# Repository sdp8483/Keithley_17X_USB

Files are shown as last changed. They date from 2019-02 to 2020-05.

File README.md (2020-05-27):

# Keithley 17x USB Adapter
The following device is used to connect the Keithley 177 and 179 digital multimeter to the PC. The USB Adapter is a serial COM port enabling the user to use simple serial terminal programs to read data from the Keithley multimeter. The device fully isolates the PC from the multimeter through optoisolators and has no impact on the meters performance. The Keithley 17x USB Adapter is a simple device for connecting two great multimeters to the PC to further increase their value to hobbyists by enabling data logging.

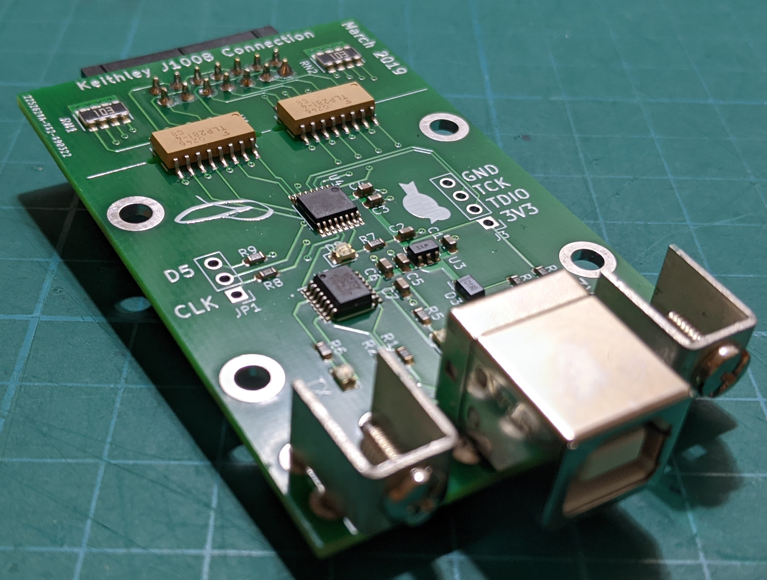
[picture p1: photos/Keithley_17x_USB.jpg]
Keithley 17x USB Adapter


 Top View | Bottom View   
----|-----    
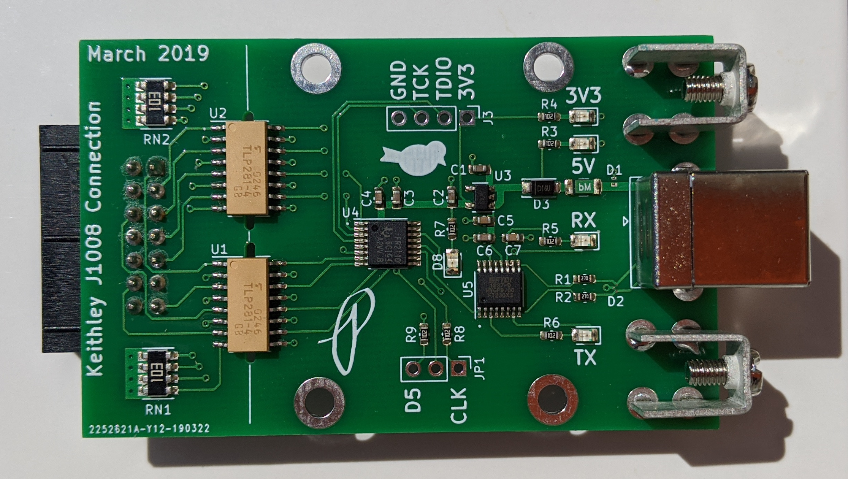
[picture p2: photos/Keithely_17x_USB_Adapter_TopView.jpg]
USB Adapter Top View
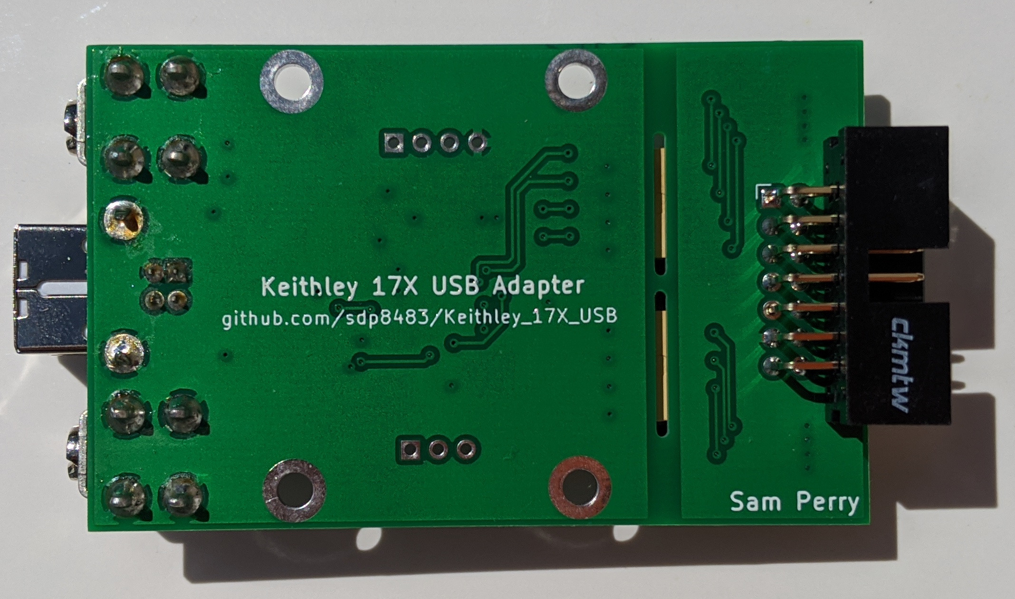
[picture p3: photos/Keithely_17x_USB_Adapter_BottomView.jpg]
USB Adapter Bottom View
 | 

The Keithley 177 and 179 Digital Multimeter have a GPIB option. If your meter has this option installed you may want to get a GPIB to USB adapter and use that. If your meter does not have this option installed then the Keithley 17x USB Adapter is for you. The original GPIB option was a daughter board that connected to the meter's main board using connector J1008. This connector is a 14 pin DIP socket located right behind the input terminals of the meter. Before continuing with the project I suggest you open up your meter and locate this connector. Below are pictures of the socket location on the three meters I have. If the socket is not soldered in but the footprint is on the PCB then don't worry. Get a suitable DIP socket and solder it in.

 Keithley 177 J1008 Location                                 | Keithley 179 J1008 Location
-------------------------------------------------------------|-------------------
177 J1008 Location| 179 J1008 Location

179 Birdseye View

# Building the PCB
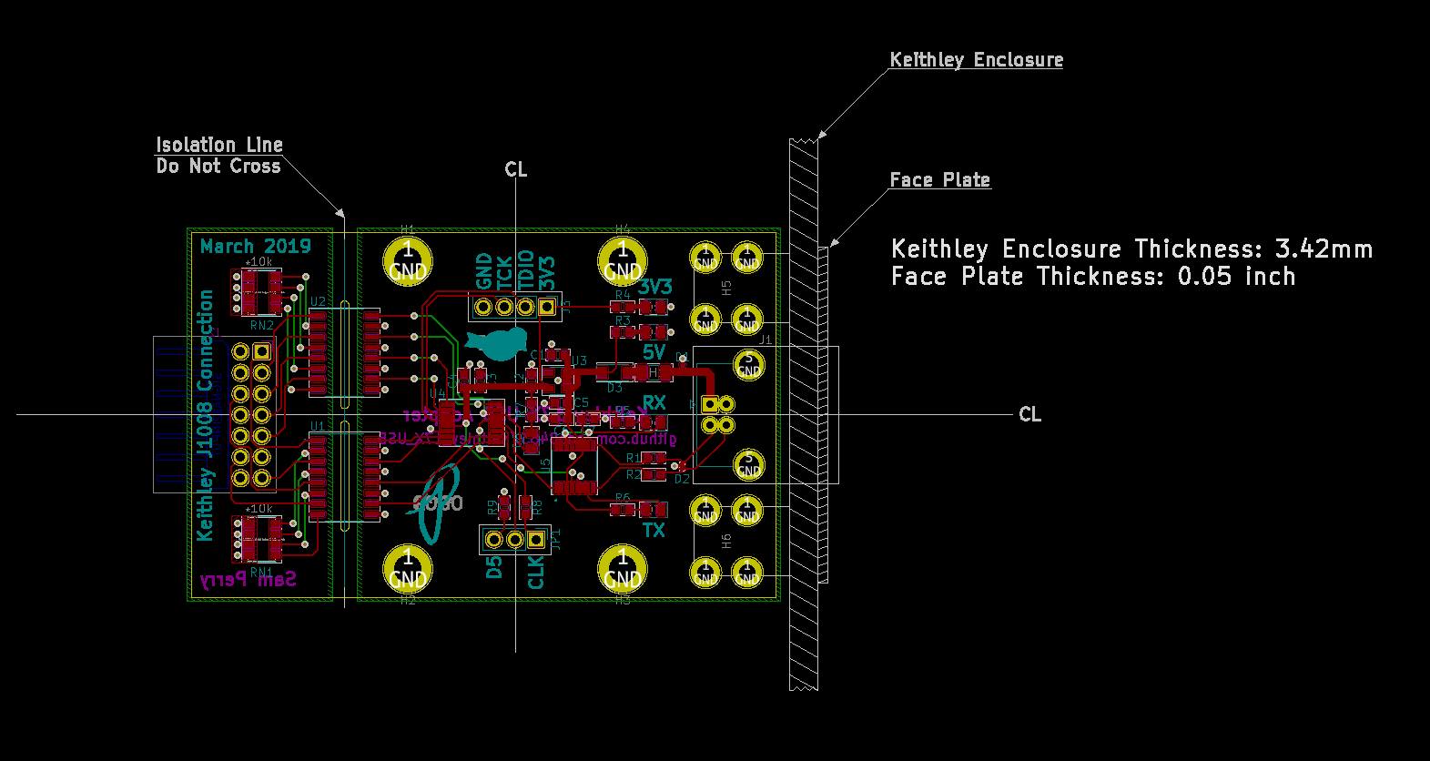
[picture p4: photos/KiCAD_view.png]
KiCAD View


1. Download the [GERBER](pcb/gerber) files and order from your favorite prototype PCB board house. The PCB is double sided and is 70.5mm x 40mm in size.

2. For reflow soldering I strongly suggest getting a solder paste stencil from your prototype PCB manufacture. If ordering thorough a board house that does not offer stencils then [OSH Stencils](https://www.oshstencils.com/#%20) is a low cost option. The polyimide film 3mil stencil is more then durable enough for a few boards and the cost is just about right. For hand soldering the solder paste stencil can be omitted.

3. Order the components listed in the [BOM](pcb/bom/Keithley_17x_USB_BOM.csv). All items were ordered from [DigiKey](https://www.digikey.com/) or [LCSC](https://lcsc.com/) but it is possible to source from other suppliers.

4. Use the [Interactive BOM](pcb/bom/ibom.html) for part placement during PCB assembly.

# Programing the MSP430FR2110
1. The lowest cost solution to obtain a programmer for the MSP430 is to buy a TI Launchpad. The [MSP-EXP430FR2433](http://www.ti.com/tool/MSP-EXP430FR2433) Launchpad is a good option but any TI Lauchpad that has an onboard eZ-FET debug probe will work.

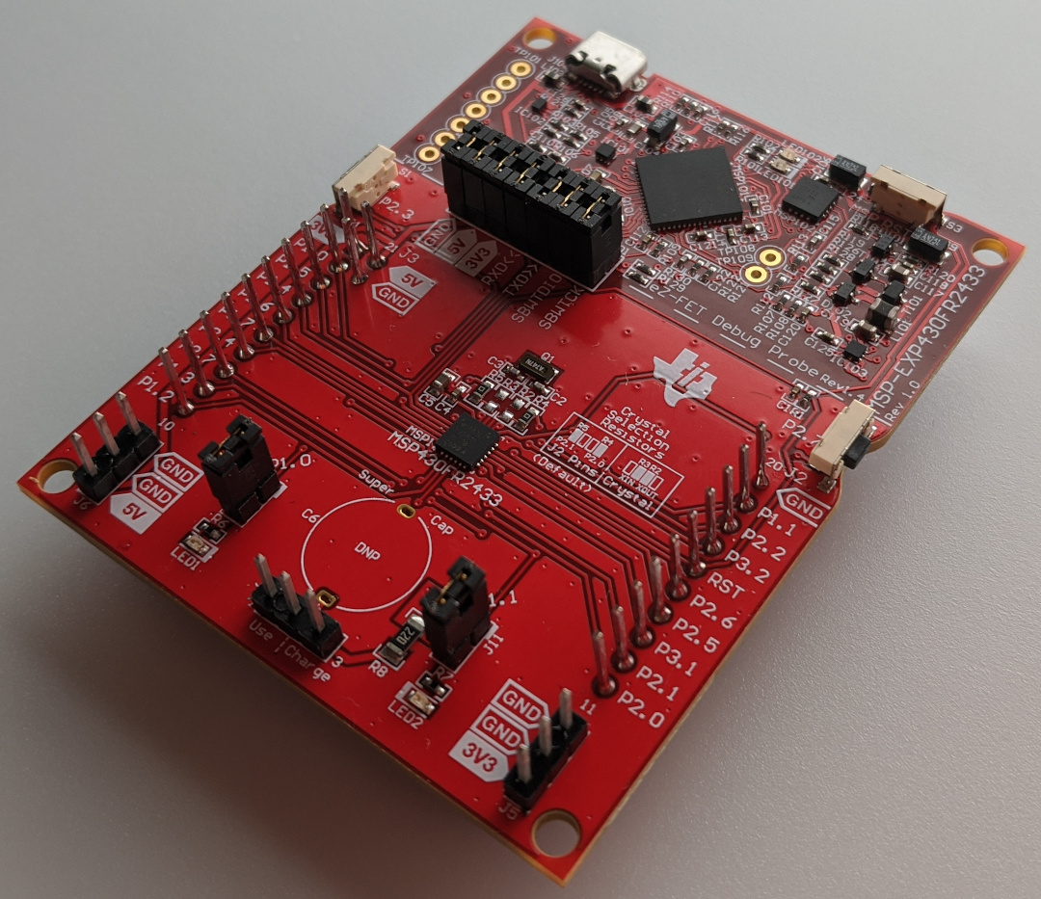
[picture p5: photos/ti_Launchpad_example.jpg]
MSP-EXP430FR2433


2. There are at least two software paths for uploading the firmware
    1. **TI UniFlash:** You can either install [UniFlash](http://www.ti.com/tool/UNIFLASH) or use the [UniFlash cloud tool](https://dev.ti.com/). The compiled code is in [firmware/releases](firmware/releases).

    2. **TI Code Composer Studio:** Install the latest version of [Code Composer Studio](http://www.ti.com/tool/CCSTUDIO), import the CCS project found in [firmware/keithley_17X_USB](firmware/keithley_17X_USB), and build the firmware yourself. There is also a [cloud version of CCS](https://dev.ti.com/) that you can use if you do not want to install software on your PC.

3. Remove all the jumpers from the TI Launchpad used to connect the eZ-FET to the onboard target microcontroller. Connect the eZ-FET to connector J3 on the Keithley 17x USB adapter. The pinout is labeled on the silkscreen. It is not necessary to solder a header onto the PCB, I programmed all my boards using female to male Dupont wires and held them in place while uploading the code.

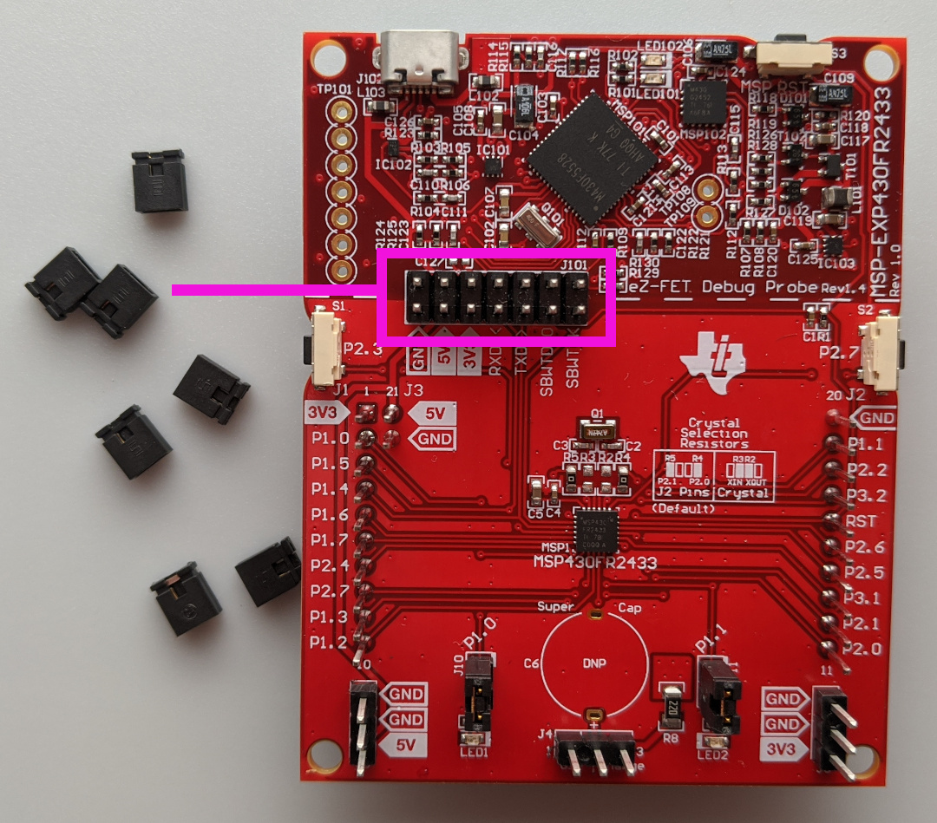
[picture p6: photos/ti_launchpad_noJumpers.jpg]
Remove Jumpers from Lauchpad


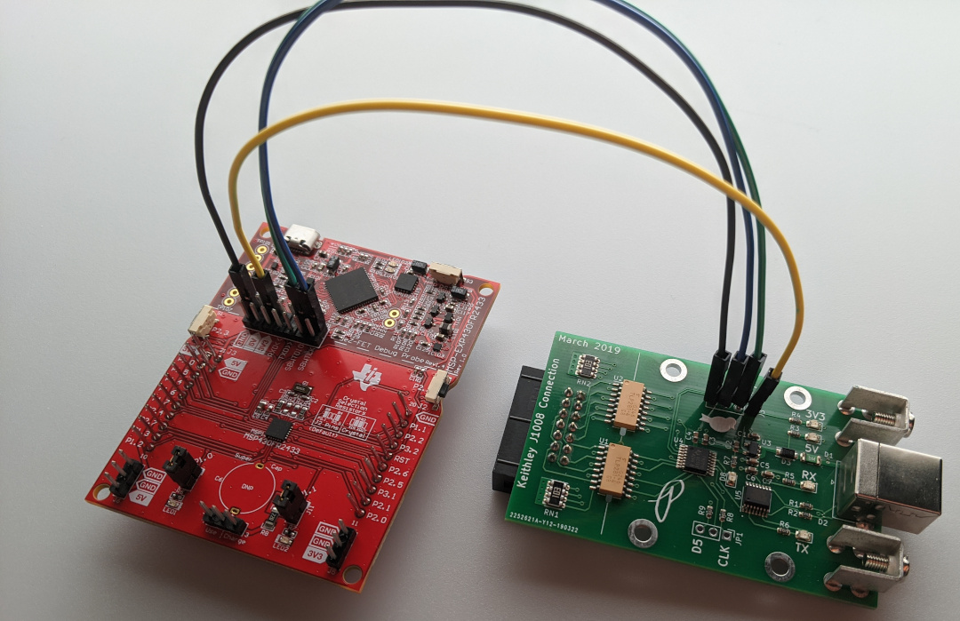
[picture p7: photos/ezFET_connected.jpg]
ezFET Connected


# Installing the USB Adapter into the Keithley Digital Multimeter
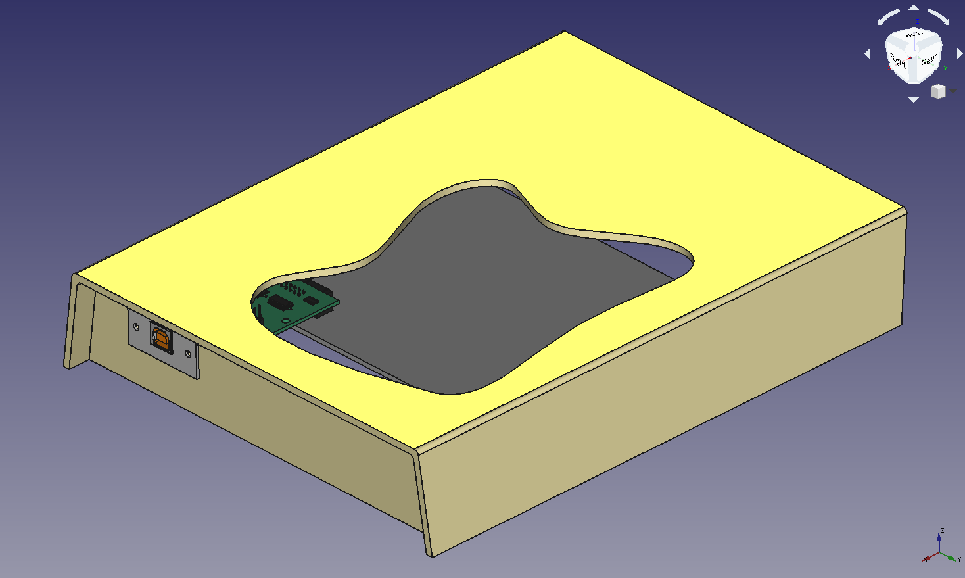
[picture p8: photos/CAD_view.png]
CAD View


1. Print and cutout the mounting hole locating [template](enclosure/Drawings/mounting_template.pdf).

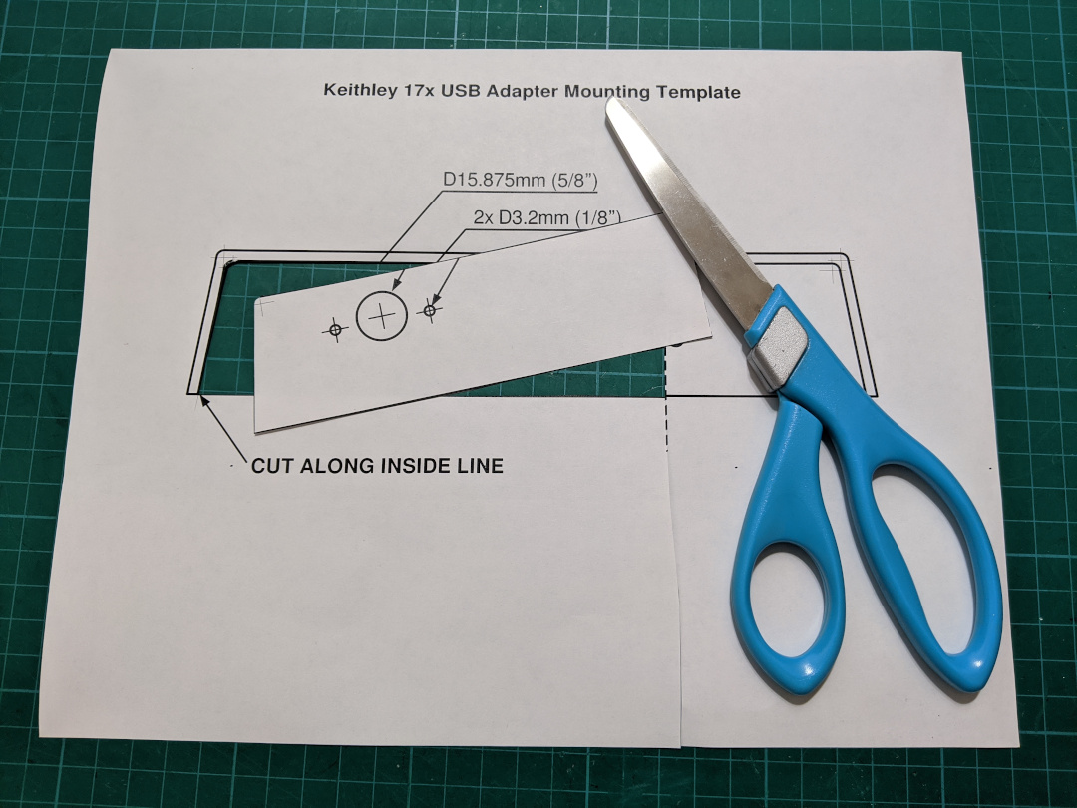
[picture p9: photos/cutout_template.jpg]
cutout template


2. Open up your digital multimeter. We need to add a few holes to the rear of the top case.

3. Using a punch and the hole locating template, mark the center of the mounting hole locations and the USB cutout.

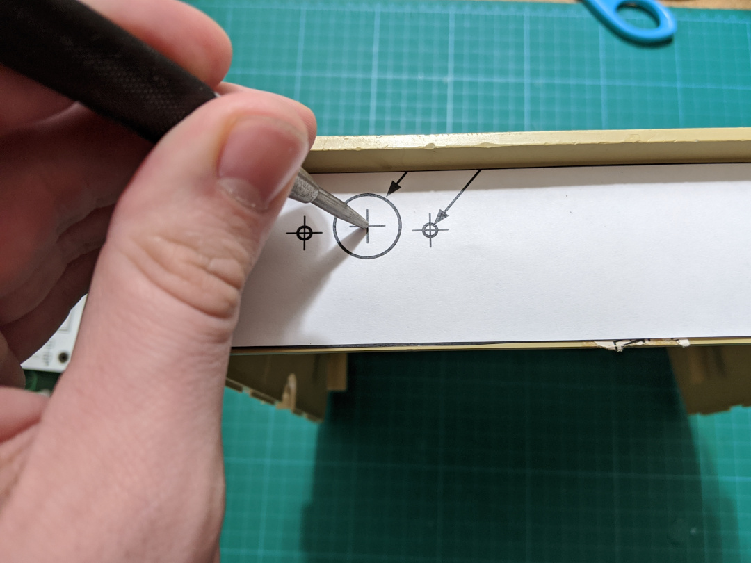
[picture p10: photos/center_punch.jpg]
center punch

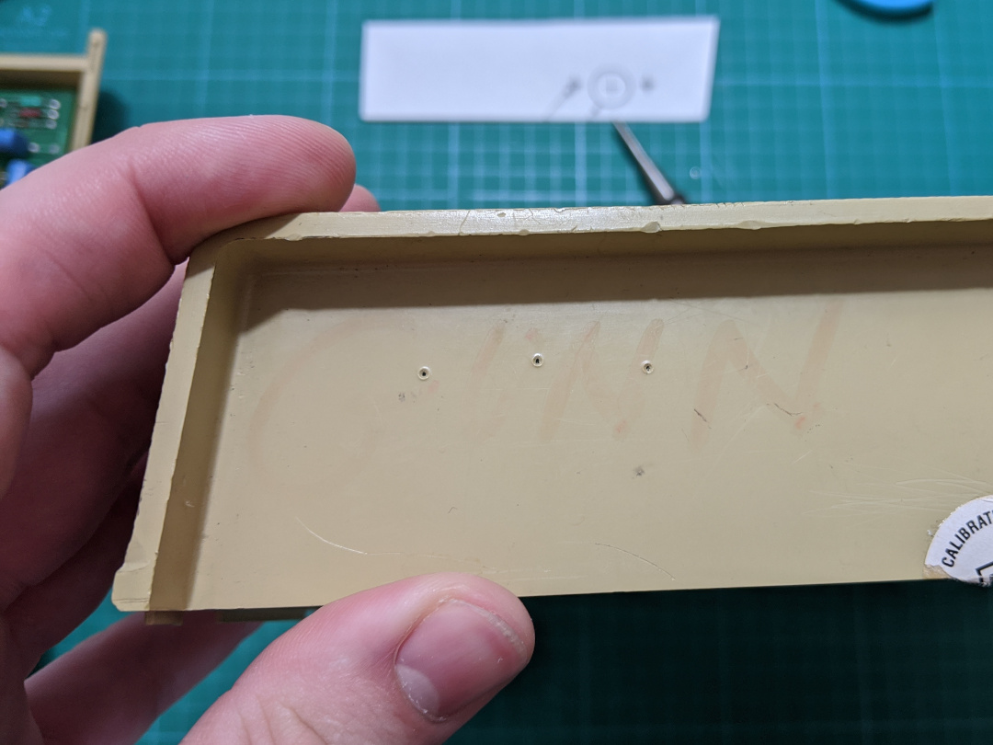
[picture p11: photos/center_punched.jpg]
center punched


4. Drill the mounting holes using a #29 [3.45mm] drill or closest metric size. Enjoy that old plastic smell coming from the fresh drilled hole.

5. I recommend pilot drilling the USB hole first, you can use the same size drill bit from the previous step. Then drill the USB cutout to 5/8" [15.875mm] or the closest metric size. I used a set of step drills so that the hole was gradually increased.
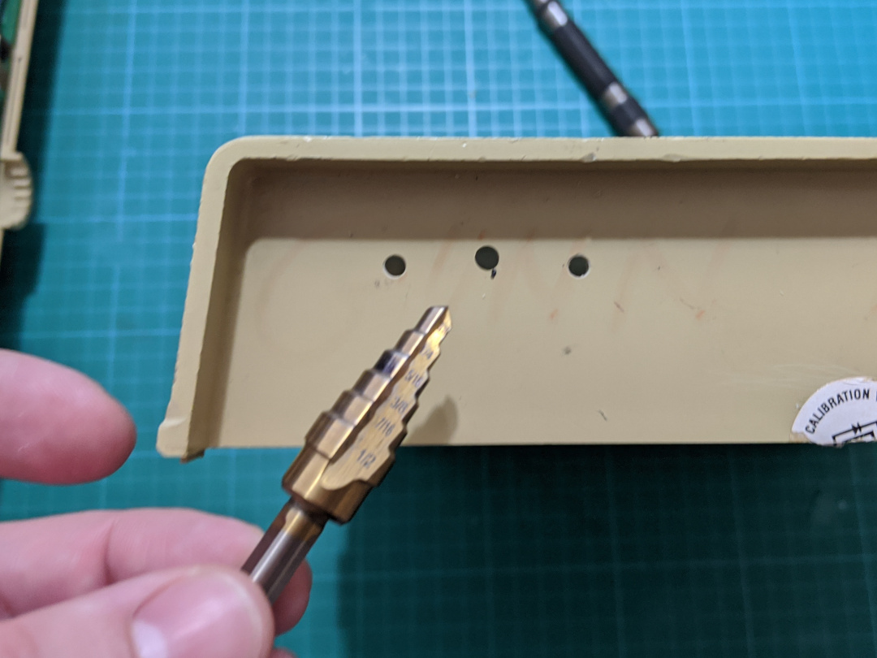
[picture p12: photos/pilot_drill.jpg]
pilot drill

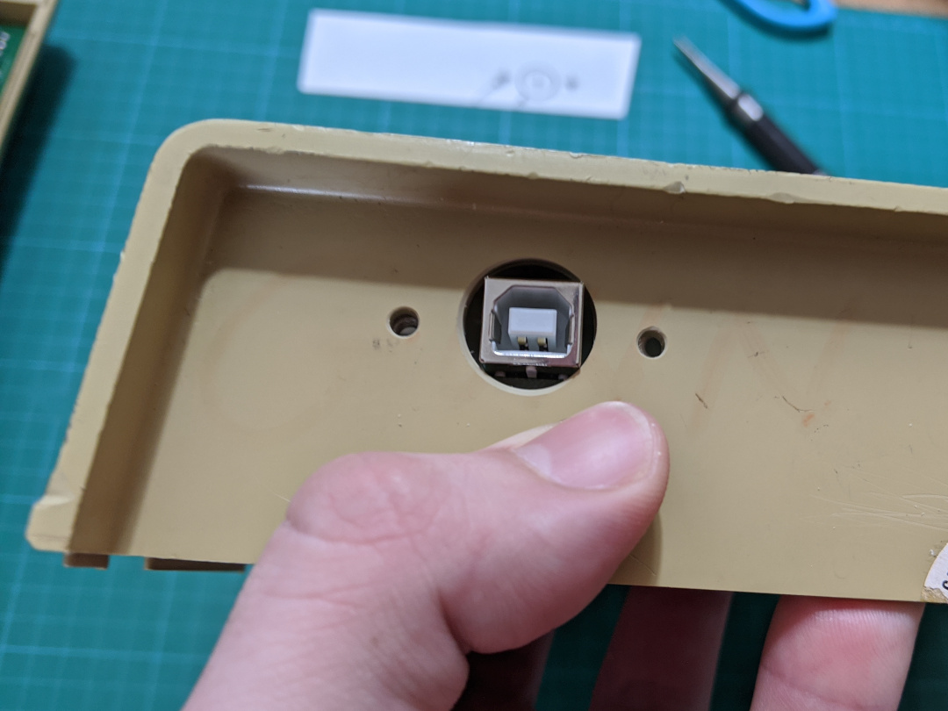
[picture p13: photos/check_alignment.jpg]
check holes


6. Don't forget to deburr the drilled holes.

7. Print off a [face plate](encloser/USB_face_plate.stl) so we can hide the gap around the circular cutout for the USB connector. Print at 0.2mm layer height. It's very thin so it should print fast, about 5 minutes on my Prusa clone. If you don't mind the gap you can skip this.

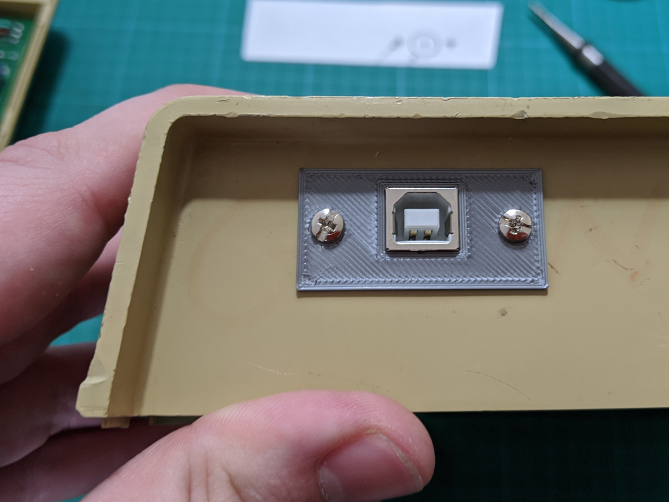
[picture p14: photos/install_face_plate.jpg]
install with faceplate


8. Place the top of the case to the right of the bottom of the multimeter.
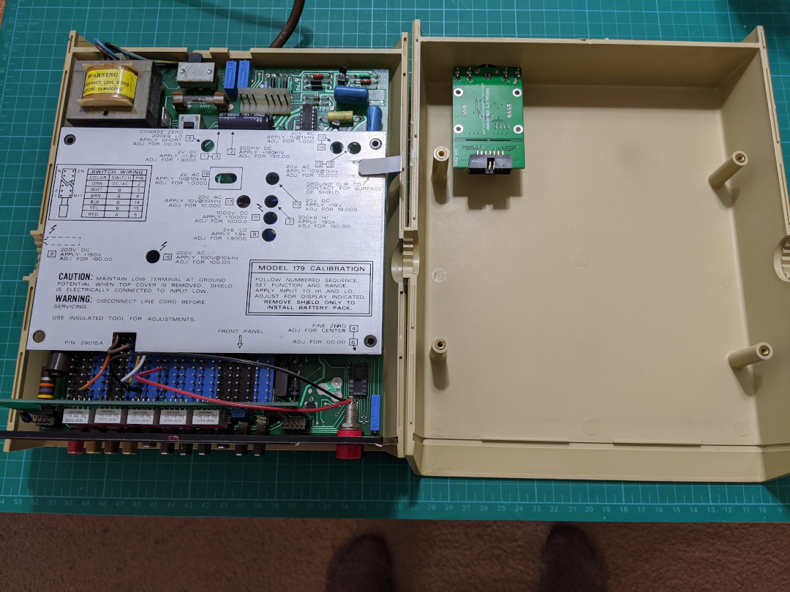
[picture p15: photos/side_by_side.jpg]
side by side


9. Install the DIP connector into the DIP socket on the multimeter main board. It's hard to see it in the photo but the DIP socket has a chamfered corner on the inside pocket to indicate pin 1. Align pin 1 of the DIP socket to pin 1 of the ribbon cable, the red stripe. Don't go by the pictures below, it seems that the placement of Pin 1 on this DIP socket is different not only between the 177 and 179 but also between the same model number.

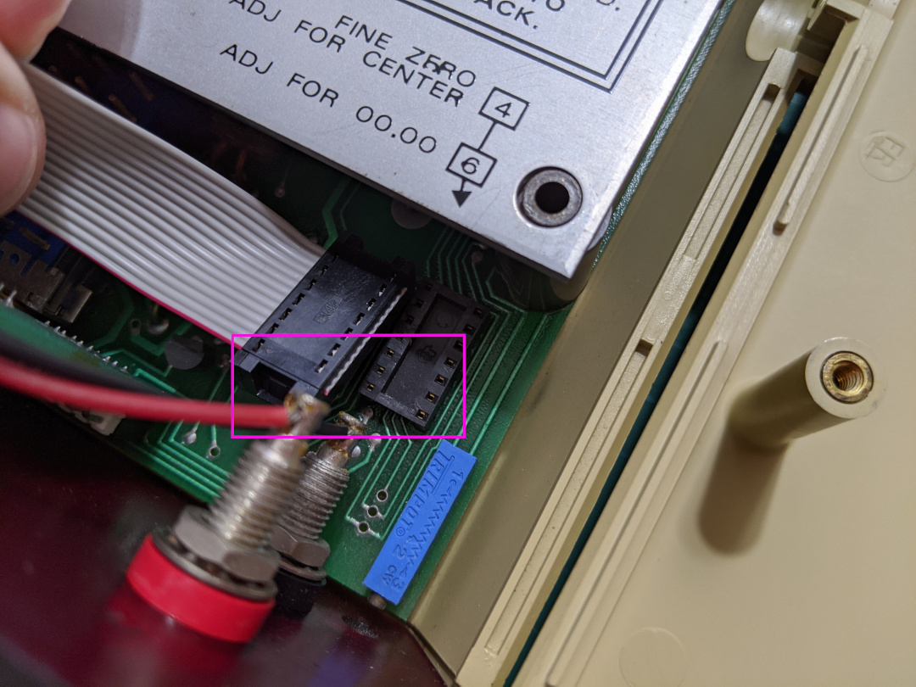
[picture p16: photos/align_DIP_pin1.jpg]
DIP pin 1

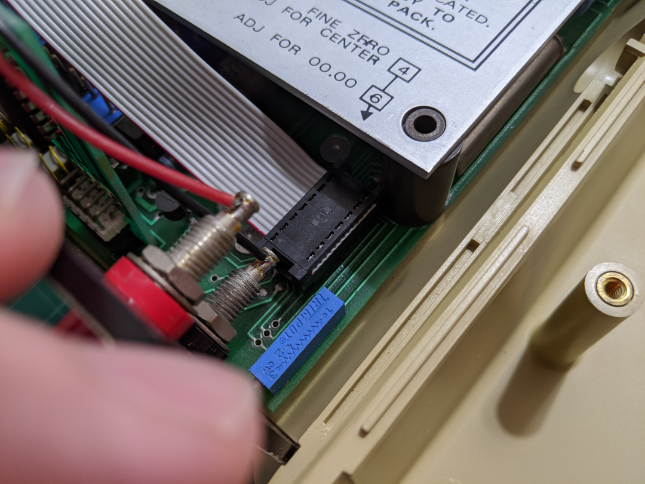
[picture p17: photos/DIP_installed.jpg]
DIP inserted


The DIP socket on my 177 was to close to the mounting pillar and required me to shave off the corner of the DIP connector.

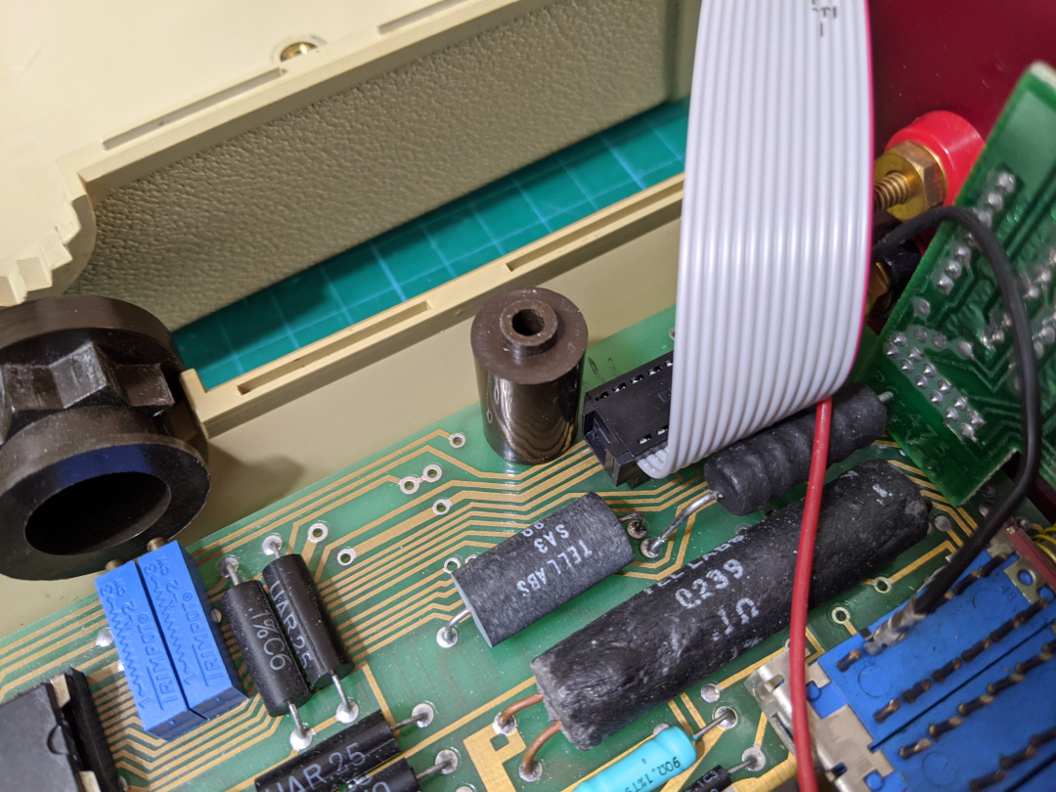
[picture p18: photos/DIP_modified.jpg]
DIP connector modified


10. Install the IDC connector on the ribbon cable. Pin 1 of the connector is indicated by a small triangle, make sure this aligns with the red stripe of the ribbon cable. Before fully attaching the IDC connector it is good to check the cable length by putting the top of the case onto the multimeter.
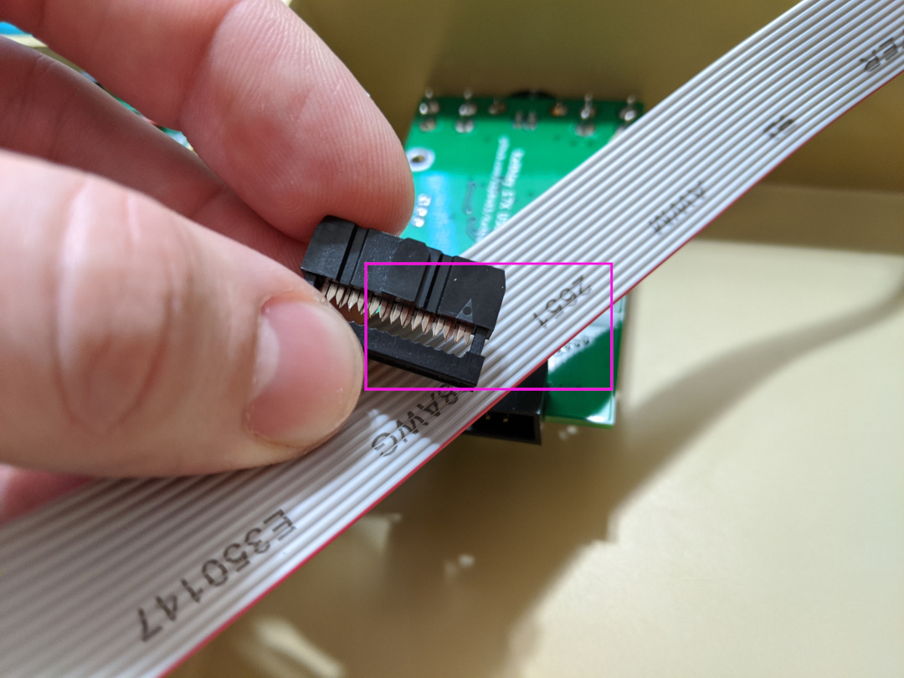
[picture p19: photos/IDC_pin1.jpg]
IDC Pin 1

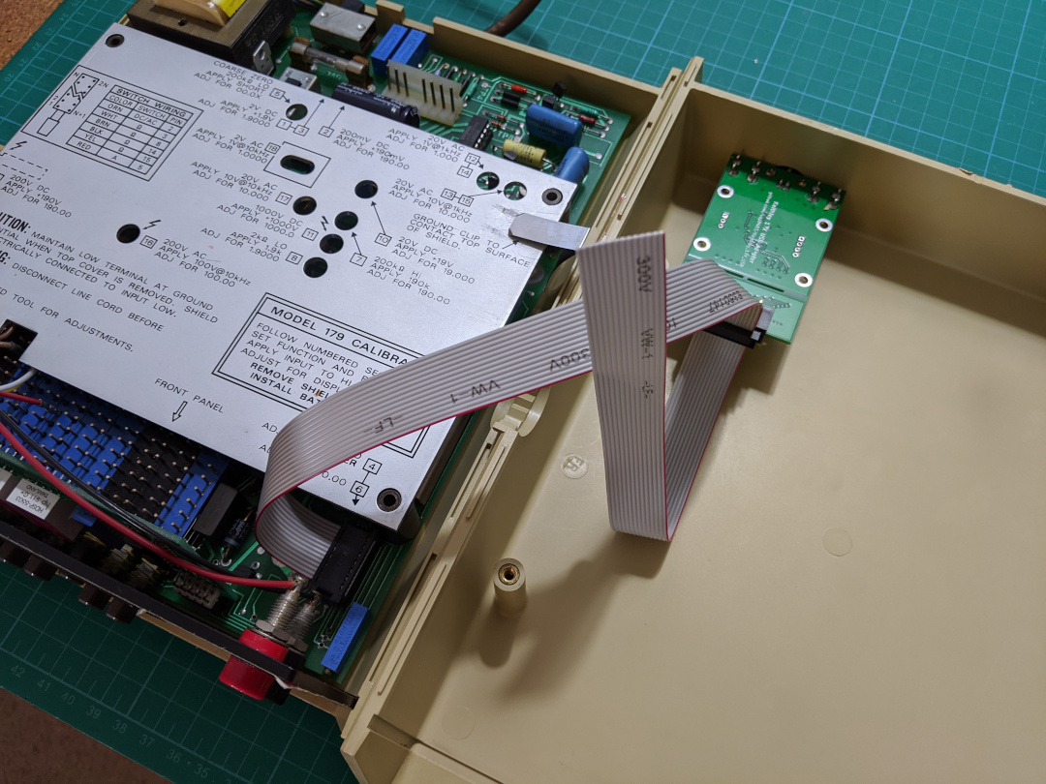
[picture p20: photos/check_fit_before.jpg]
Check Cable Length


11. Trim the ribbon cable. A hobby knife or similar tool works.
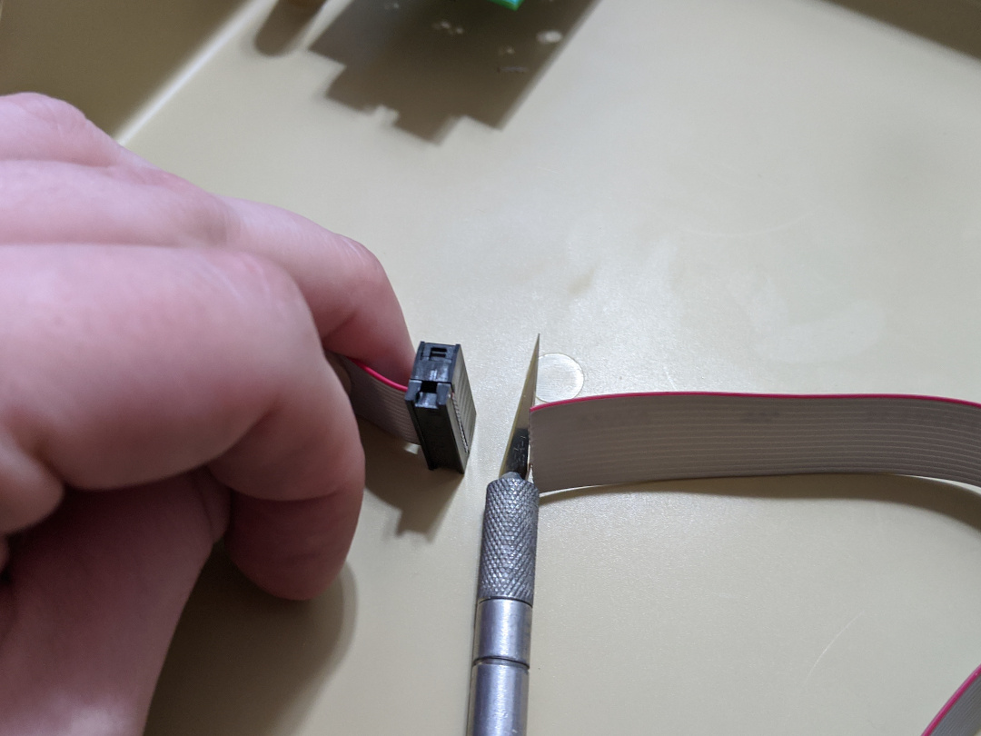
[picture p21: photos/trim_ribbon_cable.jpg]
Trim Ribbon Cable


12. Reassemble the multimeter and test it out using a serial terminal program on your PC.
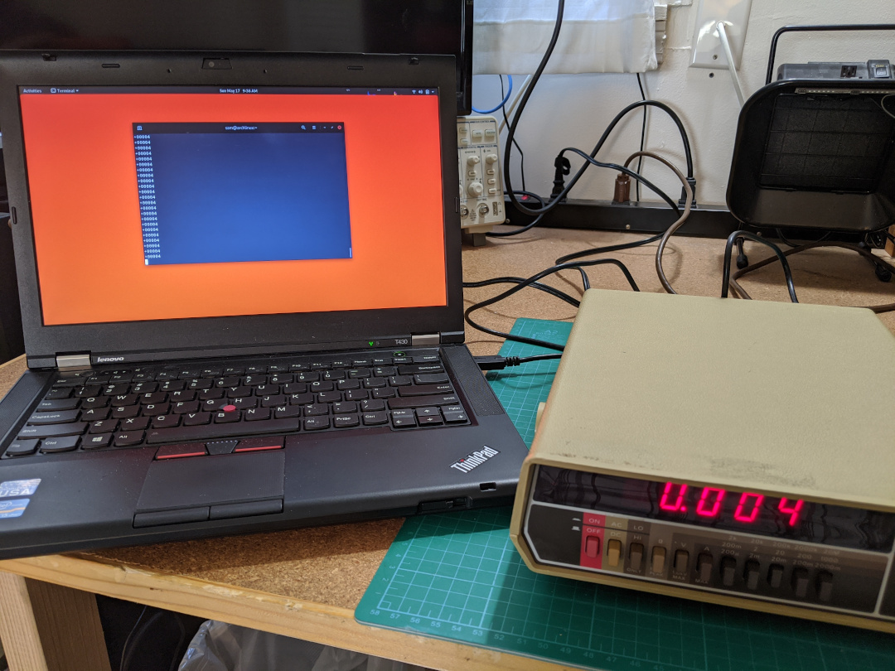
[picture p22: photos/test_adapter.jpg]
Test Communication


# PC Connection

The Keithley 17x USB Adapter uses a FTDI serial to USB converter IC. Most operating systems should come with drivers already installed. If your system does not come with FTDI drivers you will need to download and install them from [FTDI](https://www.ftdichip.com/FTDrivers.htm).

Connect to the Keithley 17x USB Adapter using any serial terminal program such as [PuTTY](https://www.putty.org/) (Windows) or [Minicom](https://en.wikipedia.org/wiki/Minicom) (Linux).  You can also use the Arduino serial monitor. The Keithley 17x USB Adapter is setup for a baud rate of 115200 8N1.

# Python GUI

If you have Python 3.x installed on your computer you can also use the [Python GUI](software/17X_UART_Receiver). Run the GUI from a terminal using the following command: `python Keithley_17X_USB/software/17X_UART_Reciever/main.py`
 
Select the model of multimeter you are connecting to. A window will popup that will let you select the serial port of the multimeter you want to connect. After connecting select the measurement units and the measurement range of the meter. The range switches on the GUI **do not** change the range on the multimeter, they simply format the GUI display to match the multimeter display. There is no way for the USB Adapter to change the range on the multimeter, it is a read only device.

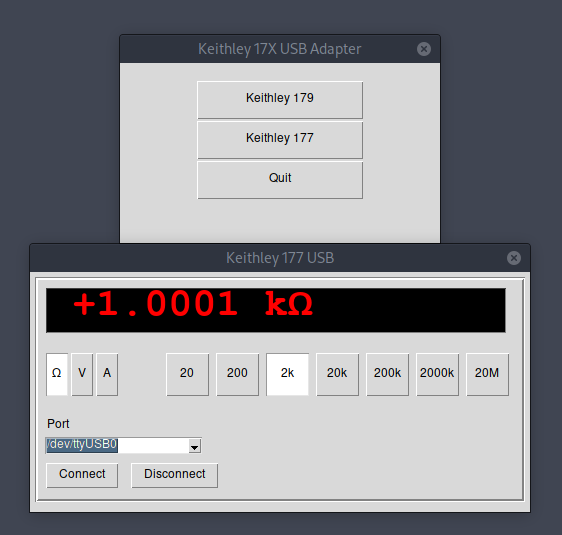
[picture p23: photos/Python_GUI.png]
Python GUI


# Theory of Operation

Below is a screenshot from the display section of the schematic for the Keithley 177, the 179 display is similar. Connector J1008 is on the right of the schematic. This connects to the data bus between the main multimeter IC U106 and the display. The USB adapter taps into this data bus to decode the data being sent to the display. 

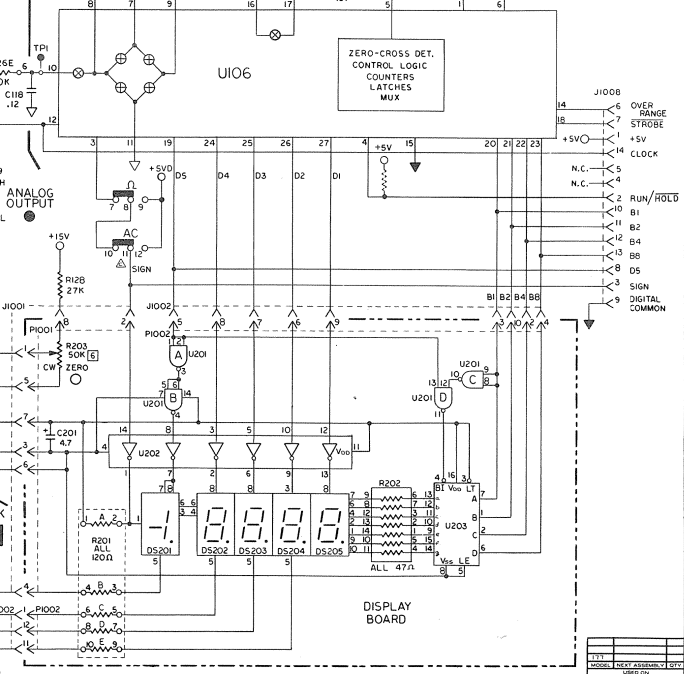
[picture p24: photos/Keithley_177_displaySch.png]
Keithley 177 Schematic


The `D5` signal is high when the fifth digit on the display is on, the fifth digit is the left most digit when looking at the display. This signal is high for 2ms. `B1`, `B2`, `B4`, and `B8` are the four bit value that this display is showing. In the logic analyzer capture below only `B1` is high therefor digit 5 is `1`. Since the other digits are not available on this data bus the USB Adapter hardware triggers off a rising `D5` signal and then uses hardware timers to sample the remaining digits which are all 2ms in length. The above example decodes to `19089`. Notice how there is no signal for the decimal place on the data bus available to the USB adapter. Since the `sign` signal is high that means that the value displayed is positive. The `overange` signal will strobe high and then low signaling that the meter is out of its measurement range, this signal was not outside of the range since I was connected to a 1.9000V reference and the meter was in its 2V range.

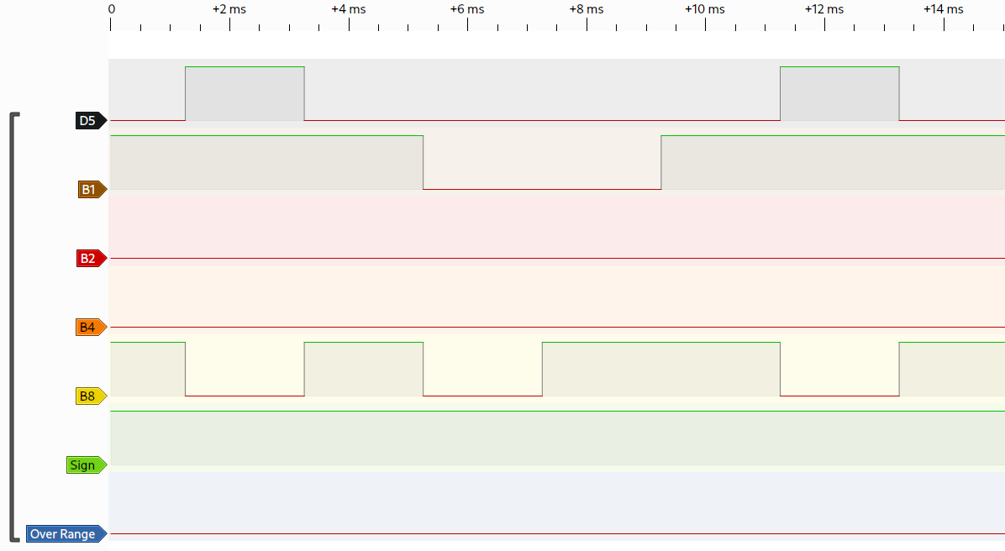
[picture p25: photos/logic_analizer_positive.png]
Logic Capture
S

What about `Clock`? The clock signal is ignored by the USB adapter since it was not consistent across the two meter models that this project was targeting. You may notice that JP1 of the USB Adapter seems like it was put there as a way to select the conversion trigger off of the `D5` or `Clock` signal. You are not wrong, that was my original intent but I found it was easier to only trigger off of `D5`.

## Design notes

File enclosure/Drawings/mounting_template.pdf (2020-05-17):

Keithley 17x USB Adapter Mounting Template

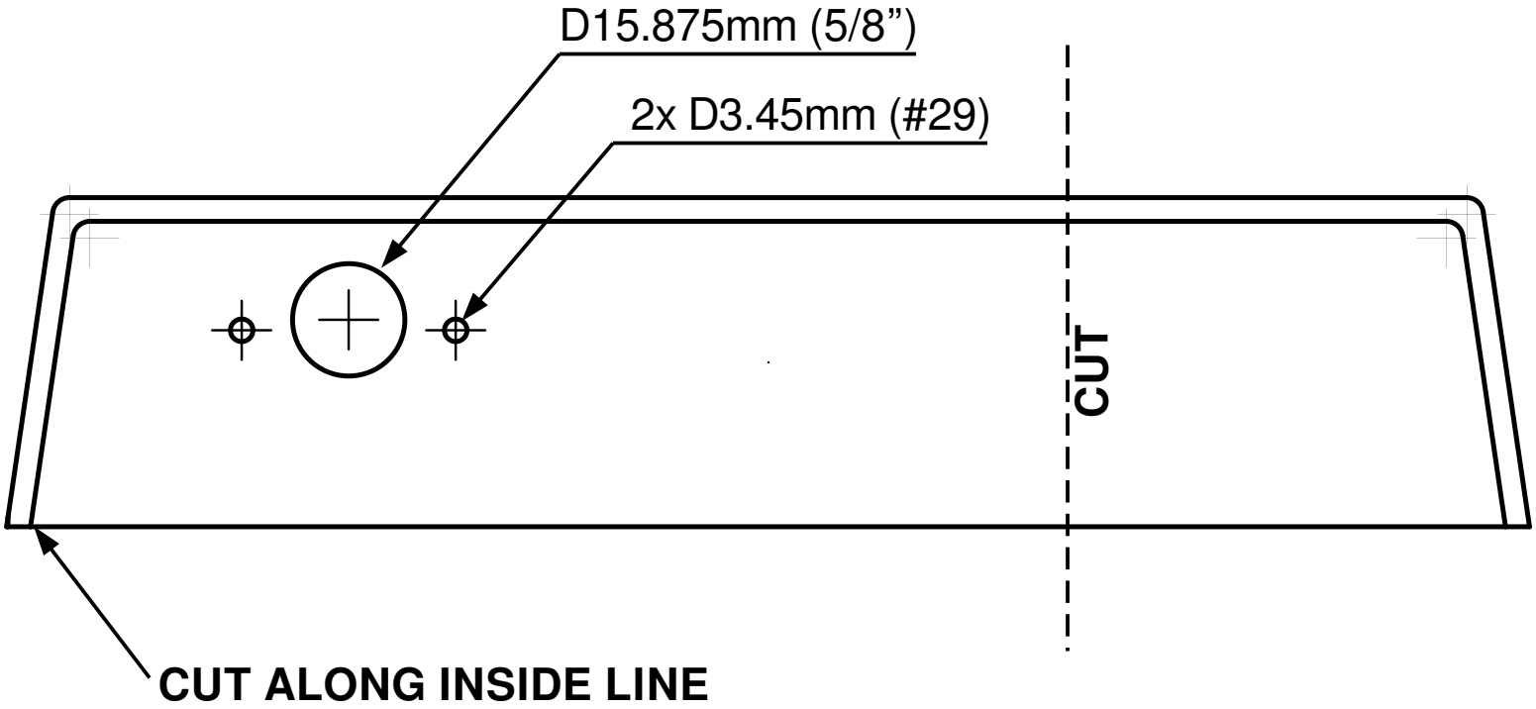
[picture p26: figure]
CUT ALONG INSIDE LINE

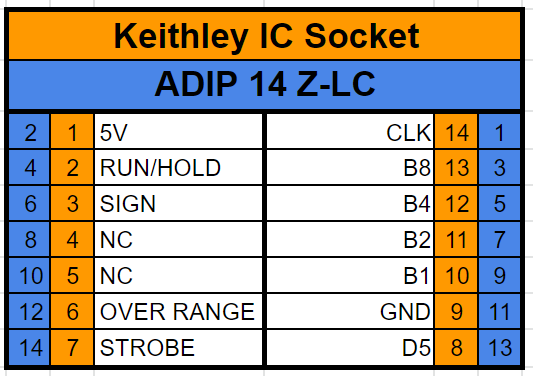
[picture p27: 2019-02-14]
pcb/images/Keithley IC Socket Pinout.PNG

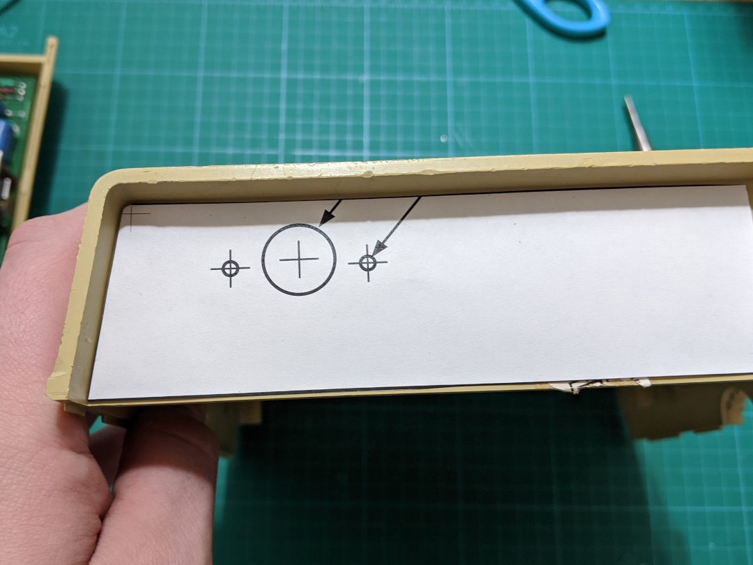
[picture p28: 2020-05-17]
photos/template_placment.jpg

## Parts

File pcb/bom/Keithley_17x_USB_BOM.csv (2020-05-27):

References | Description | Manufacture | Mfg Part Number | Supplier | Supplier Part Number | Value | Footprint | Quantity
C4, C5, C7 | CAP CER 0.1UF 25V Y5V 0603 | KEMET | C0603C104Z3VACTU | Digi-Key | 399-1100-1-ND | 100nF | C_0603_1608Metric | 3
C1, C2, C3 | CAP CER 1UF 6.3V X5R 0603 | Samsung Electro-Mechanics | CL10A105KQ8NNNC | Digi-Key | 1276-1036-1-ND | 1uF | C_0603_1608Metric | 3
C6 | CAP CER 4.7UF 6.3V X5R 0603 | Samsung Electro-Mechanics | CL10A475KQ8NNNC | Digi-Key | 1276-1045-1-ND | 4.7uF | C_0603_1608Metric | 1
R1, R2 | RES 27 OHM 5% 1/10W 0603 | Stackpole Electronics Inc | RMCF0603JT27R0 | Digi-Key | RMCF0603JT27R0CT-ND | 27R | R_0603_1608Metric | 2
R3, R4, R5, R6, R7, R8, R9 | RES SMD 1K OHM 5% 1/10W 0603 | Yageo | RC0603JR-071KL | Digi-Key | 311-1.0KGRCT-ND | 1k | R_0603_1608Metric | 7
D4, D5, D6, D7, D8 | Red 615~630nm 0805 Light Emitting Diodes (LED) RoHS | Foshan NationStar Optoelectronics | NCD0805R1 | LCSC | C84256 | 5V, 3V3, RXLED, TXLED, READ | LED_0805_2012Metric | 5
D3 | SCHOTTKY 60V SOD-123FL | SMC Diode Solutions | DSS16UTR | Digi-Key | 1655-1929-1-ND | DSS16UTR | D_SOD-123FL | 1
D1 | TVS DIODE 5.5V 14V 2X1SON | Texas Instruments | TPD1E10B06QDPYRQ1 | Digi-Key | 296-45327-1-ND | TPD1E10B06 | TI_PX1SON_DPY | 1
D2 | TVS DIODE 8.4VC 2.5A IPP 3X2SON | Texas Instruments | ESD122DMXR | Digi-Key | 296-48543-1-ND | ESD122DMXR | TI_DMX_X2SON | 1
U4 | IC MCU 16BIT 2KB FRAM 16TSSOP | Texas Instruments | MSP430FR2110IPW16R | Digi-Key | 296-47343-1-ND | MSP430FR2110 | TSSOP-16_4.4x5mm_P0.65mm | 1
U3 | IC REG LINEAR 3.3V 300MA SOT23-5 | Microchip Technology | MIC5504-3.3YM5-TR | Digi-Key | 576-4764-1-ND | MIC5504-3.3YM5 | SOT-23-5 | 1
U5 | IC USB SERIAL BASIC UART 16SSOP | FTDI, Future Technology Devices International Ltd | FT230XS-R | Digi-Key | 768-1135-1-ND | FT230XS | SSOP-16_3.9x4.9mm_P0.635mm | 1
U1, U2 | OPTOISO 2.5KV 4CH TRANS 16-SOP | Toshiba Semiconductor and Storage | TLP281-4(GB-TP,J,F |  |  | TLP281-4 | SOIC-16_4.55x10.3mm_P1.27mm | 2
TH1 | PTC RESET FUSE 8V 500MA 1206 | Bel Fuse Inc. | 0ZCJ0050FF2G | Digi-Key | 507-1802-1-ND | 0ZCJ0050FF2G | Fuse_1206_3216Metric | 1
RN1, RN2 | RES ARRAY 4 RES 10K OHM 2012 | Yageo | YC324-JK-0710KL | Digi-Key | YC324J-10KCT-ND | 10k | YC324-JK-0710KL | 2
H5, H6 | TERM SCREW M3 4 PIN PCB RA | Keystone Electronics | 7761 | Digi-Key | 36-7761-ND | M3_RA | Keystone_Screw-Terminal_7761_RightAngle | 2
J1 | CONN RCPT TYPEB 4POS R/A | Pulse Electronics Network | E8144-B02022-L | Digi-Key | 553-2272-ND | USB_B | USB_B_OST_USB-B1HSxx_Horizontal | 1
J2 | CONN HEADER R/A 14POS 2.54MM | On Shore Technology Inc. | 302-R141 | Digi-Key | ED10534-ND | SIGNAL INPUT | PinHeader_2x07_P2.54mm_Horizontal | 1
 | DIP CABLE - HDP14S/AE14G/X | Assmann WSW Components | H2PXS-1418G | Digi-Key | H2PXS-1418G-ND |  |  | 1
 | IDCconnector 14 | Ckmtw(Shenzhen Cankemeng) | C146586 | LCSC | C146586 |  |  | 1

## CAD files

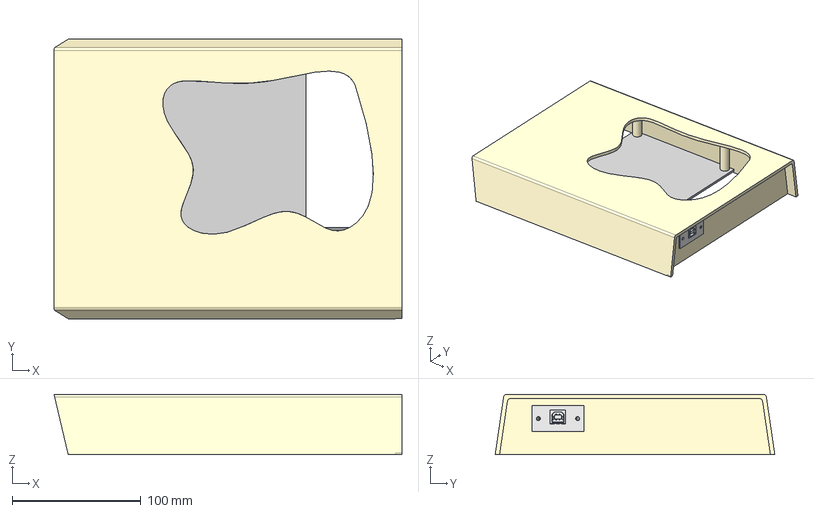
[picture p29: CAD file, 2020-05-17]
enclosure/FreeCAD/Keithley_17X_USB_Assembly.FCStd
270.0 x 217.0 x 46.9 mm
Keithley_17X_USB_PCBA_01
Keithley_17X_USB_Bottom_01
Keithley_17X_USB_Top_01
Keithley_17X_Instrument_Case_Top_01
Keithley_17X_Instrument_Calibration_Shield_01
Keithley_17X_USB_Face_01

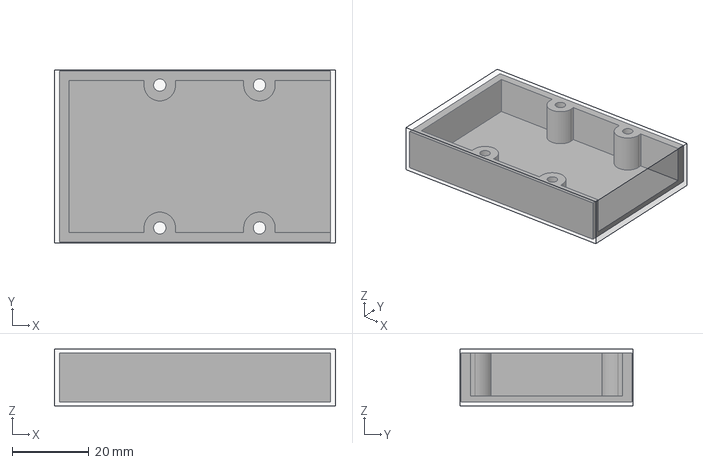
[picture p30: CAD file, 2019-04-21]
enclosure/CAM/CAM_Keithley_17X_USB_Top.FCStd
73.0 x 44.9 x 14.7 mm
Base-Body
Stock

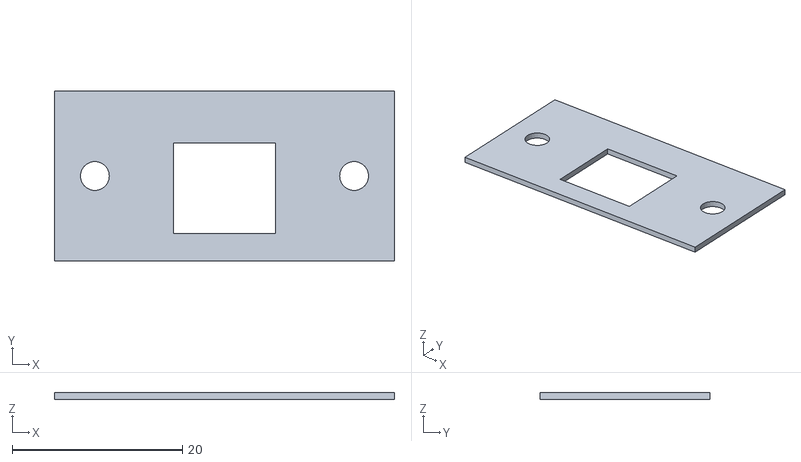
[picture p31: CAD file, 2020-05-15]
enclosure/USB_face_plate.stl
40.0 x 20.0 x 0.8

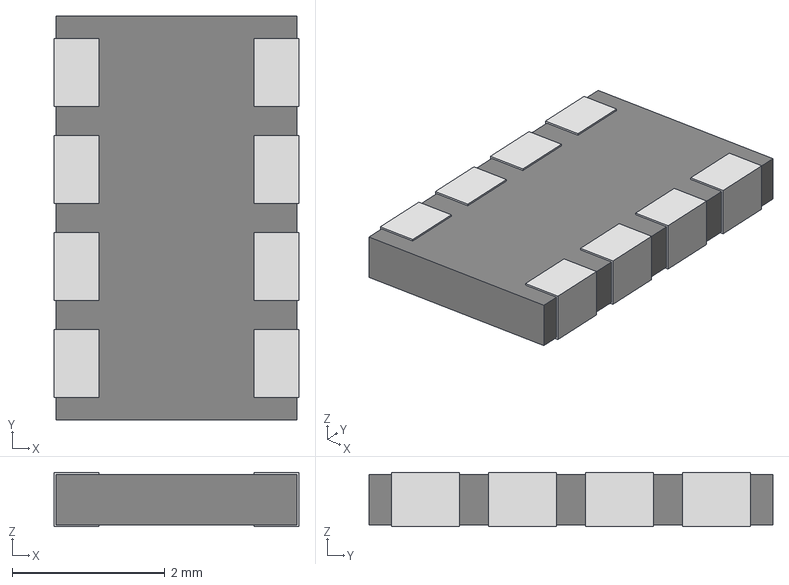
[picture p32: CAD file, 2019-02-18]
pcb/3d_models/R_Array/YAG_YC324.step
3.20 x 5.28 x 0.712 mm

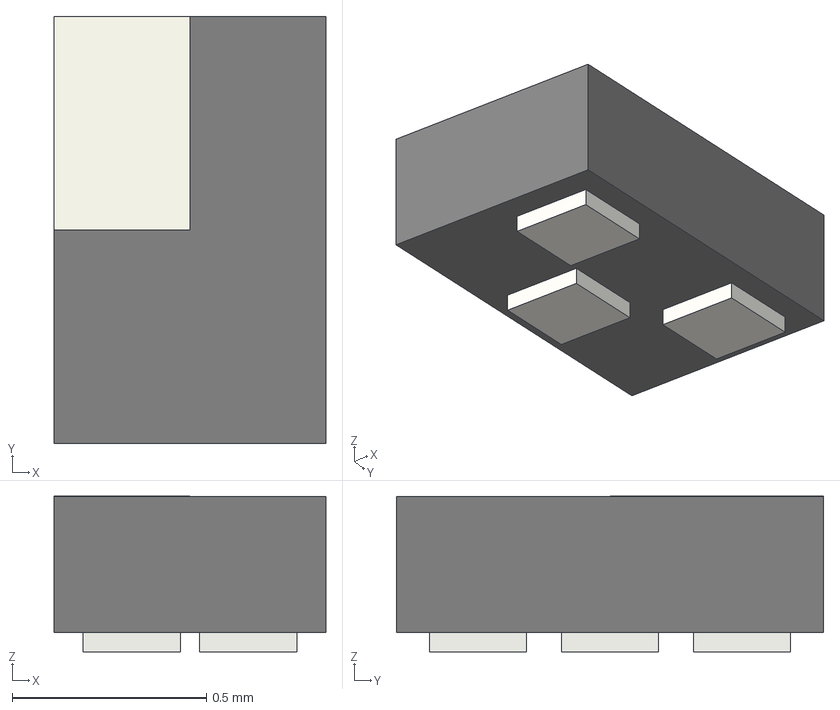
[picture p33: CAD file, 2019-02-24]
pcb/3d_models/TI_XSON_DMX.step
0.7 x 1.10 x 0.401 mm

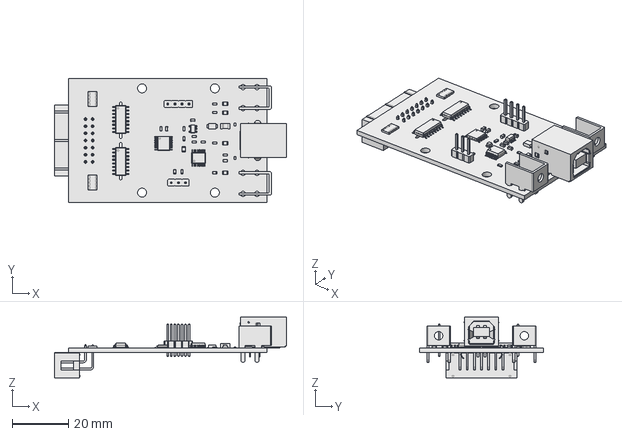
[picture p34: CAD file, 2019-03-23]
pcb/pcb_render/Keithley_17X_USB_PCBA.FCStd
82.6 x 44.0 x 21.6 mm

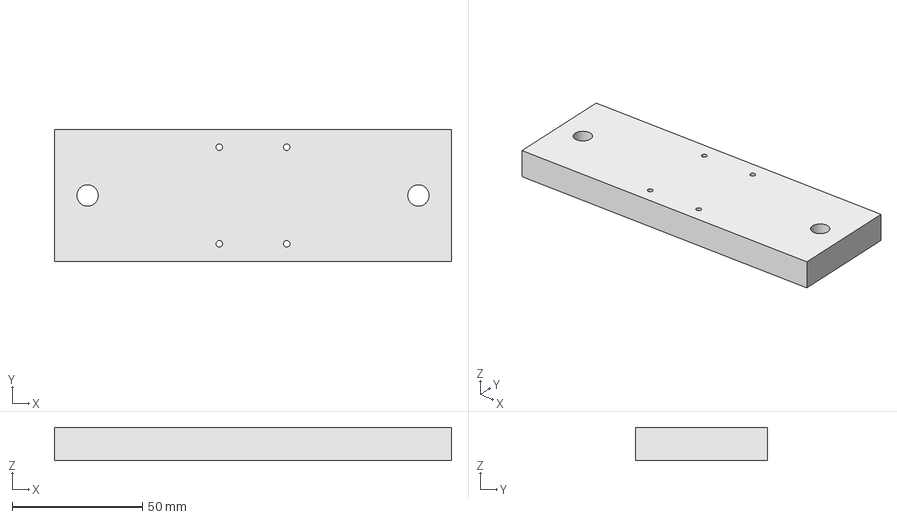
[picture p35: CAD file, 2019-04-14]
enclosure/CAM/Machining_Fixture.FCStd
152.4 x 50.8 x 12.7 mm

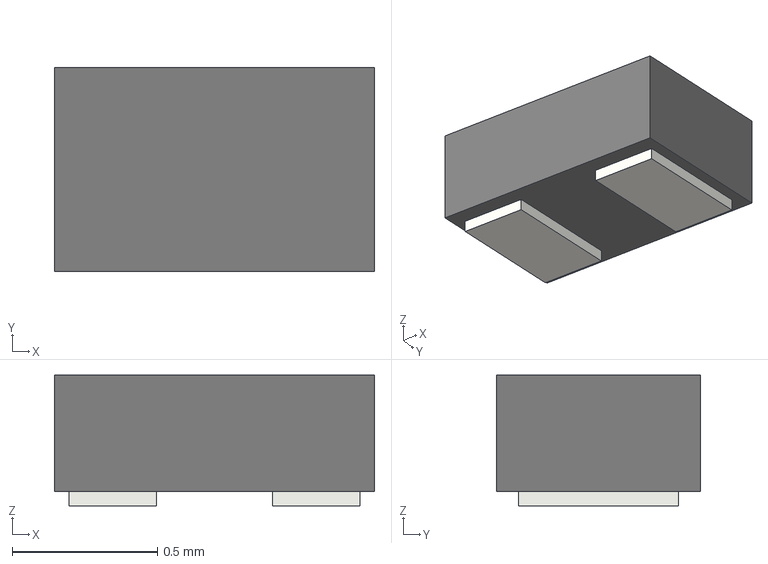
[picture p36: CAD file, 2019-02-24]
pcb/3d_models/TI_PX1SON.step
1.10 x 0.7 x 0.45 mm

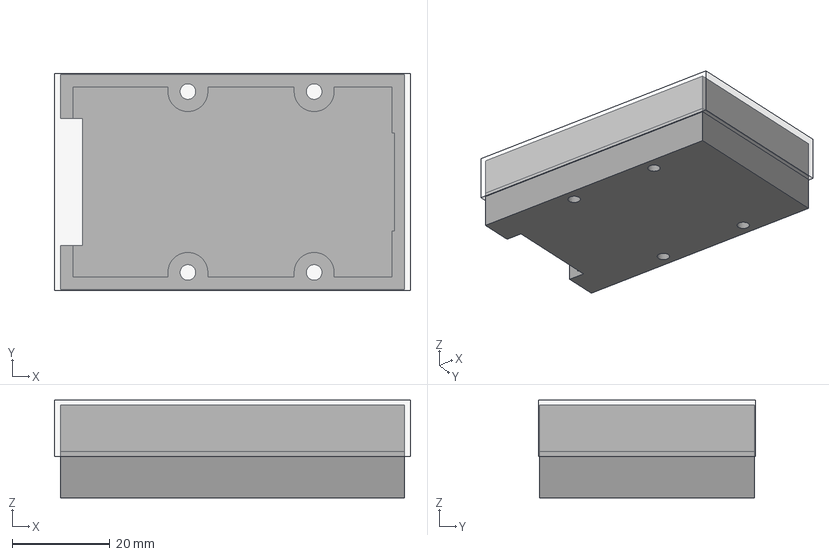
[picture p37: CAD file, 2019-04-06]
enclosure/CAM/CAM_Keithley_17X_USB_Bottom.FCStd
73.0 x 44.5 x 20.1 mm
Base-Body
Stock

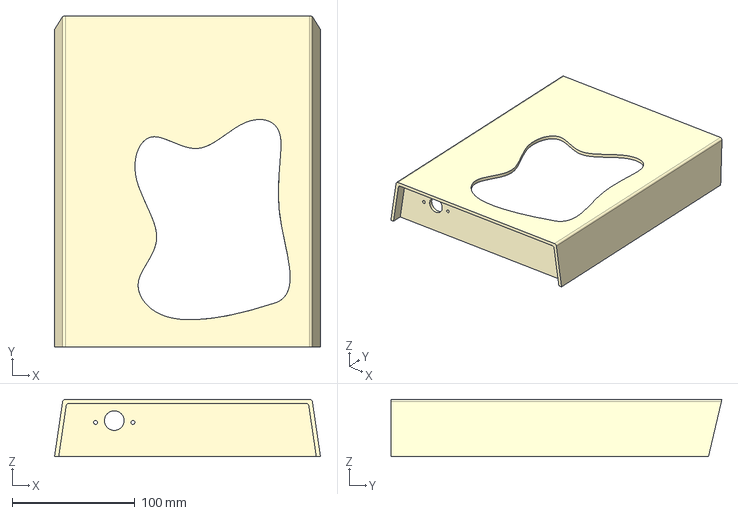
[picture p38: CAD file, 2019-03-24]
enclosure/FreeCAD/Keithley_17X_Instrument_Case_Top.FCStd
217.0 x 270.0 x 46.9 mm

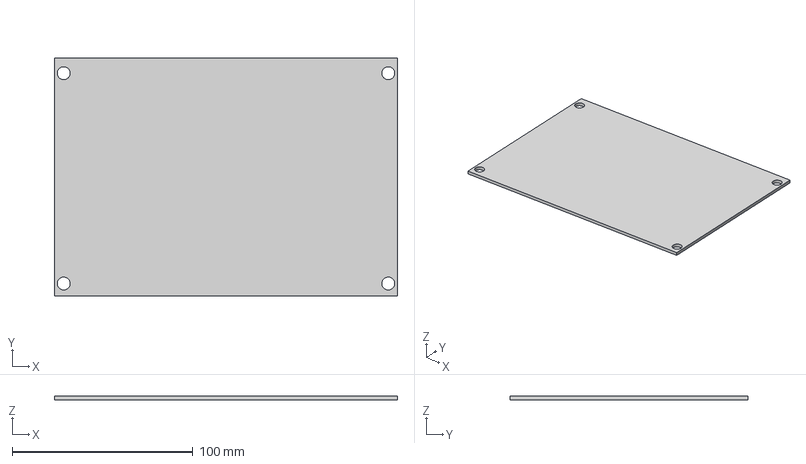
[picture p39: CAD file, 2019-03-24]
enclosure/FreeCAD/Keithley_17X_Instrument_Calibration_Shield.FCStd
190.0 x 132.0 x 2.30 mm

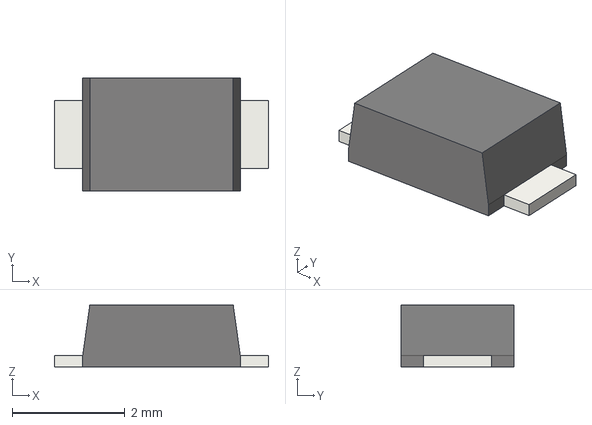
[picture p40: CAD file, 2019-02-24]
pcb/3d_models/SMC_DSS16UTR.step
3.80 x 2.00 x 1.10 mm

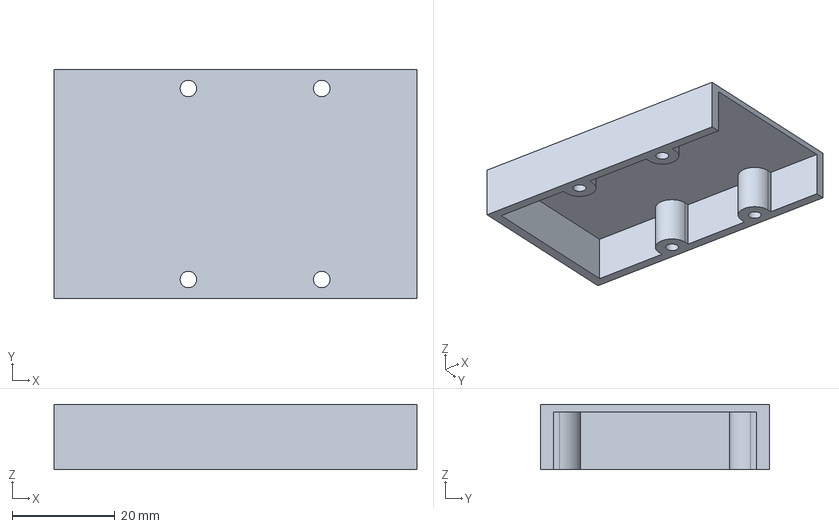
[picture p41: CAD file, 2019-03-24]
enclosure/FreeCAD/Keithley_17X_USB_Top.FCStd
70.5 x 44.4 x 12.7 mm

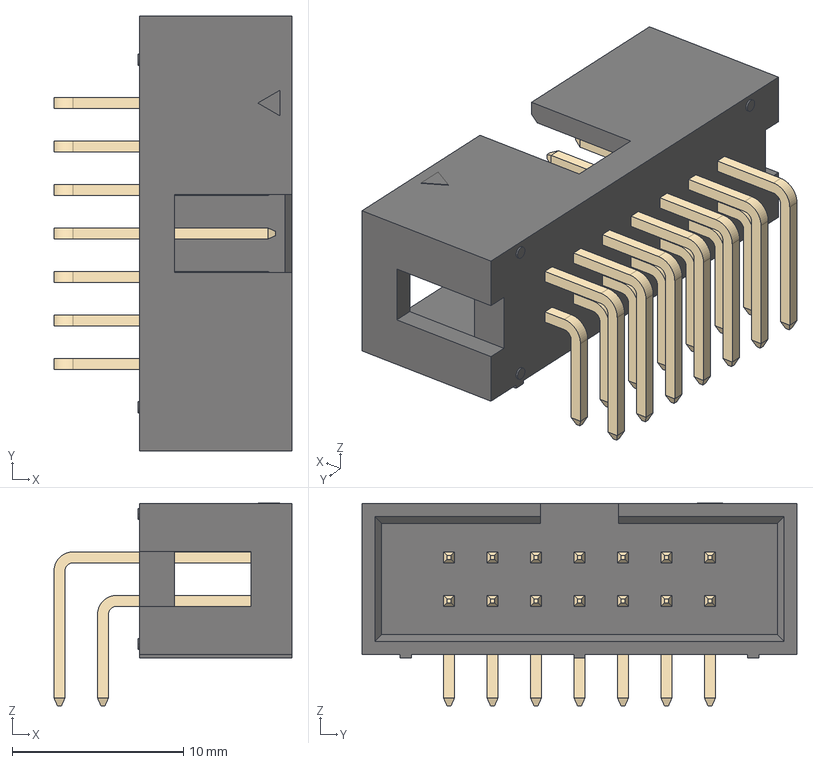
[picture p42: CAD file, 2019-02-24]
pcb/3d_models/Header_14pos_2rows_RightAngle_Shrouded.step
13.9 x 25.4 x 11.8 mm

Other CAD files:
enclosure/FreeCAD/Keithley_17X_USB_Face.FCStd
pcb/3d_models/R_Array/YAG_YC324-L.step
pcb/3d_models/R_Array/YAG_YC324-M.step
pcb/3d_models/YAG_YC324.step
enclosure/FreeCAD/Keithley_17X_USB_Bottom.FCStd
enclosure/USB_face_plate.amf
pcb/3d_models/0ZCJ.FCStd
pcb/3d_models/0ZCJ.step
pcb/3d_models/Header_14pos_2rows_RightAngle_Shrouded.FCStd
pcb/3d_models/Keystone_7761.FCStd
pcb/3d_models/Keystone_7761.step
pcb/3d_models/SMC_DSS16UTR.FCStd
pcb/3d_models/SOIC-16_3.9x9.9mm_P1.27mm.step
pcb/3d_models/TI_PX1SON.FCStd
pcb/3d_models/TI_XSON_DMX.FCStd
pcb/3d_models/USB_B_RightAngle.FCStd
pcb/3d_models/USB_B_RightAngle.step
pcb/3d_models/YAG_YC324.FCStd

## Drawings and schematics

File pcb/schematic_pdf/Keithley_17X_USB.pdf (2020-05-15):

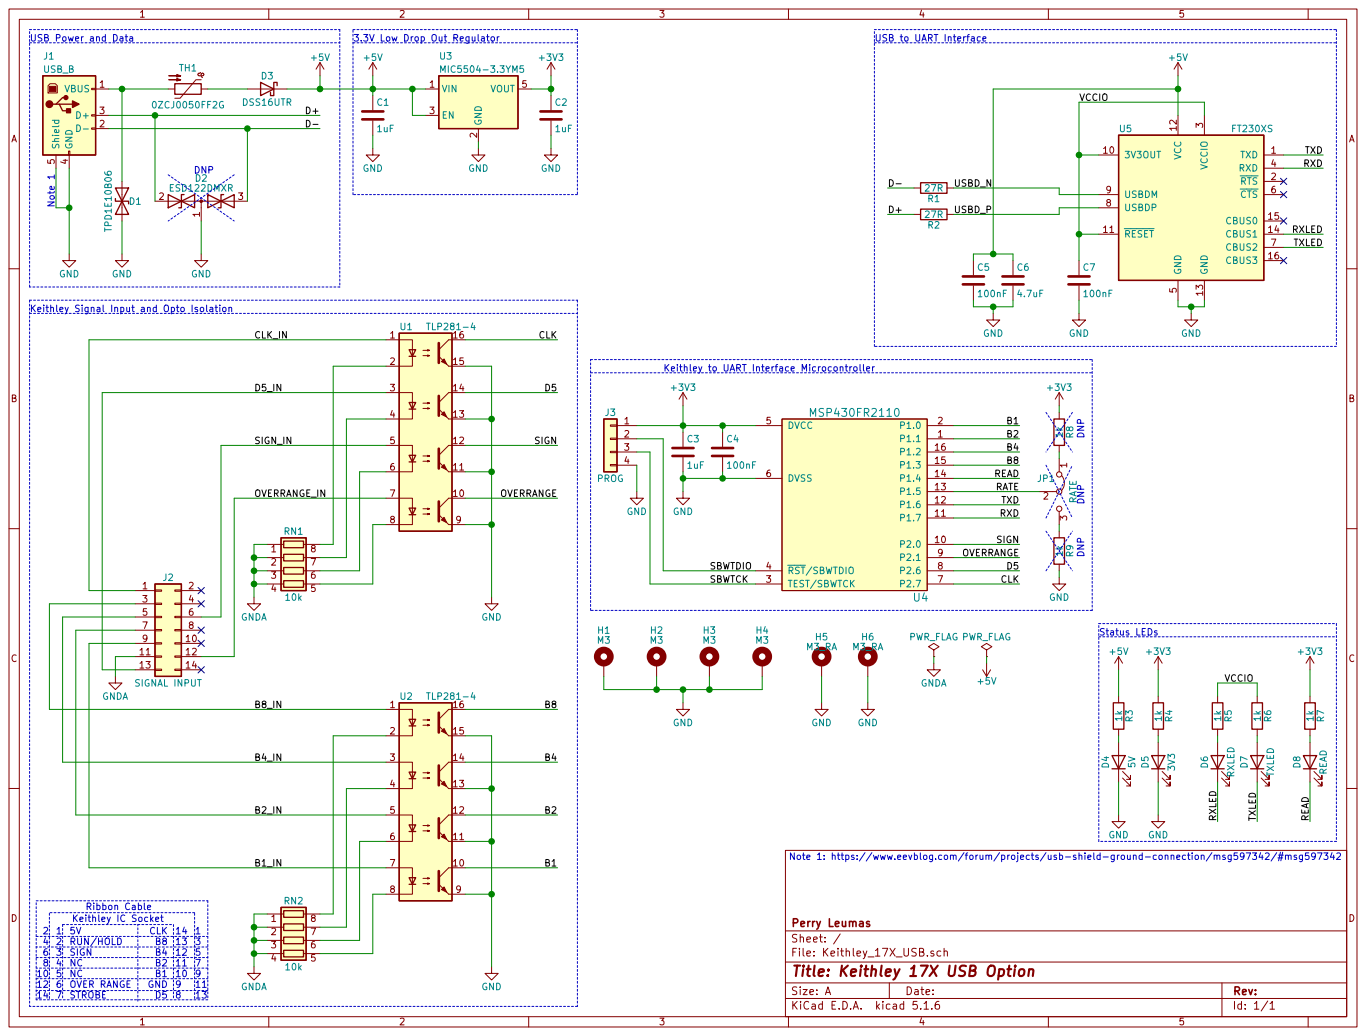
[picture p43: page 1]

3.3V Low Drop Out Regulator

Keithley Signal Input and Opto Isolation Note 1

SIGN_IN | 4

5 | J2 SIGNAL INPUT GNDA | 6

9 | | 10
11 | | 12
13 | | 14

Note 1: https://www.eevblog.com/forum/projects/usb-shield-ground-connection/msg597342/#msg597342

D5 Keithley IC Socket Ribbon Cable

File: Keithley_17X_USB.sch Sheet: / Perry Leumas

6 | 3 | SIGN | B8B4B2B1 GND | 12 | 5

8 | 4 | NC | | 11 | 7
10 | 5 | NCOVER RANGE | | 10 | 9
12 | 6 | | | 9 | 11
14 | 7 | STROBE | | 8 | 13

Id: 1/1 Title: Keithley 17X USB Option

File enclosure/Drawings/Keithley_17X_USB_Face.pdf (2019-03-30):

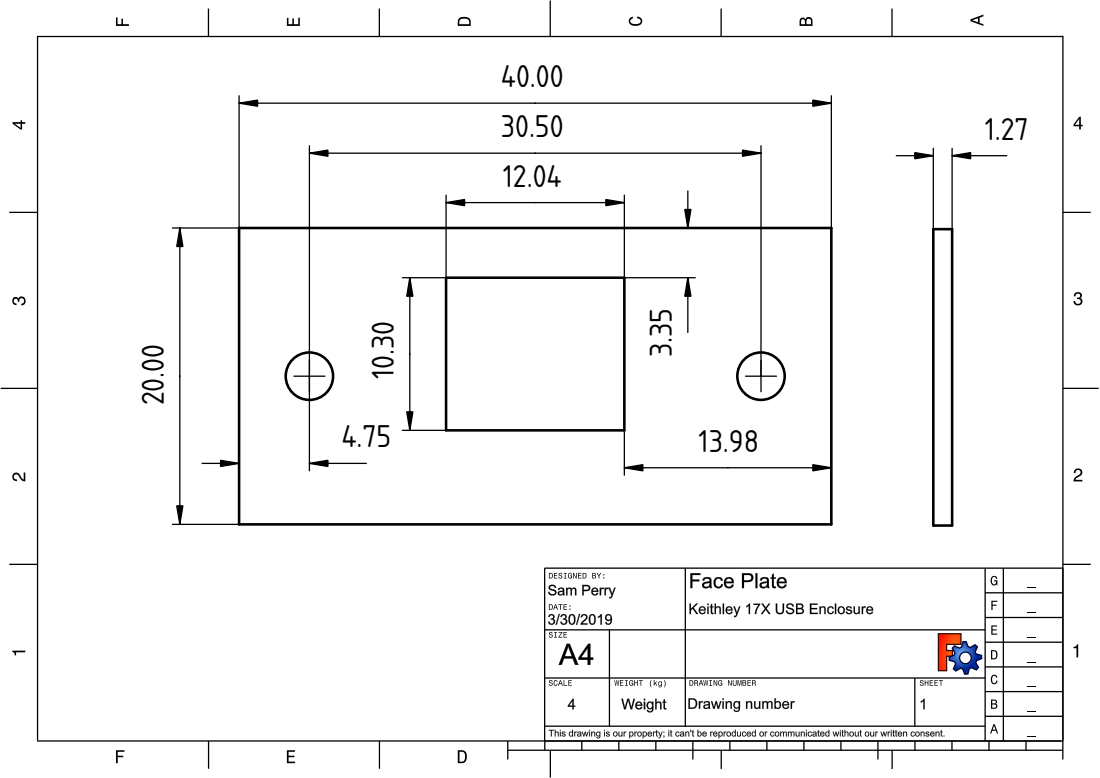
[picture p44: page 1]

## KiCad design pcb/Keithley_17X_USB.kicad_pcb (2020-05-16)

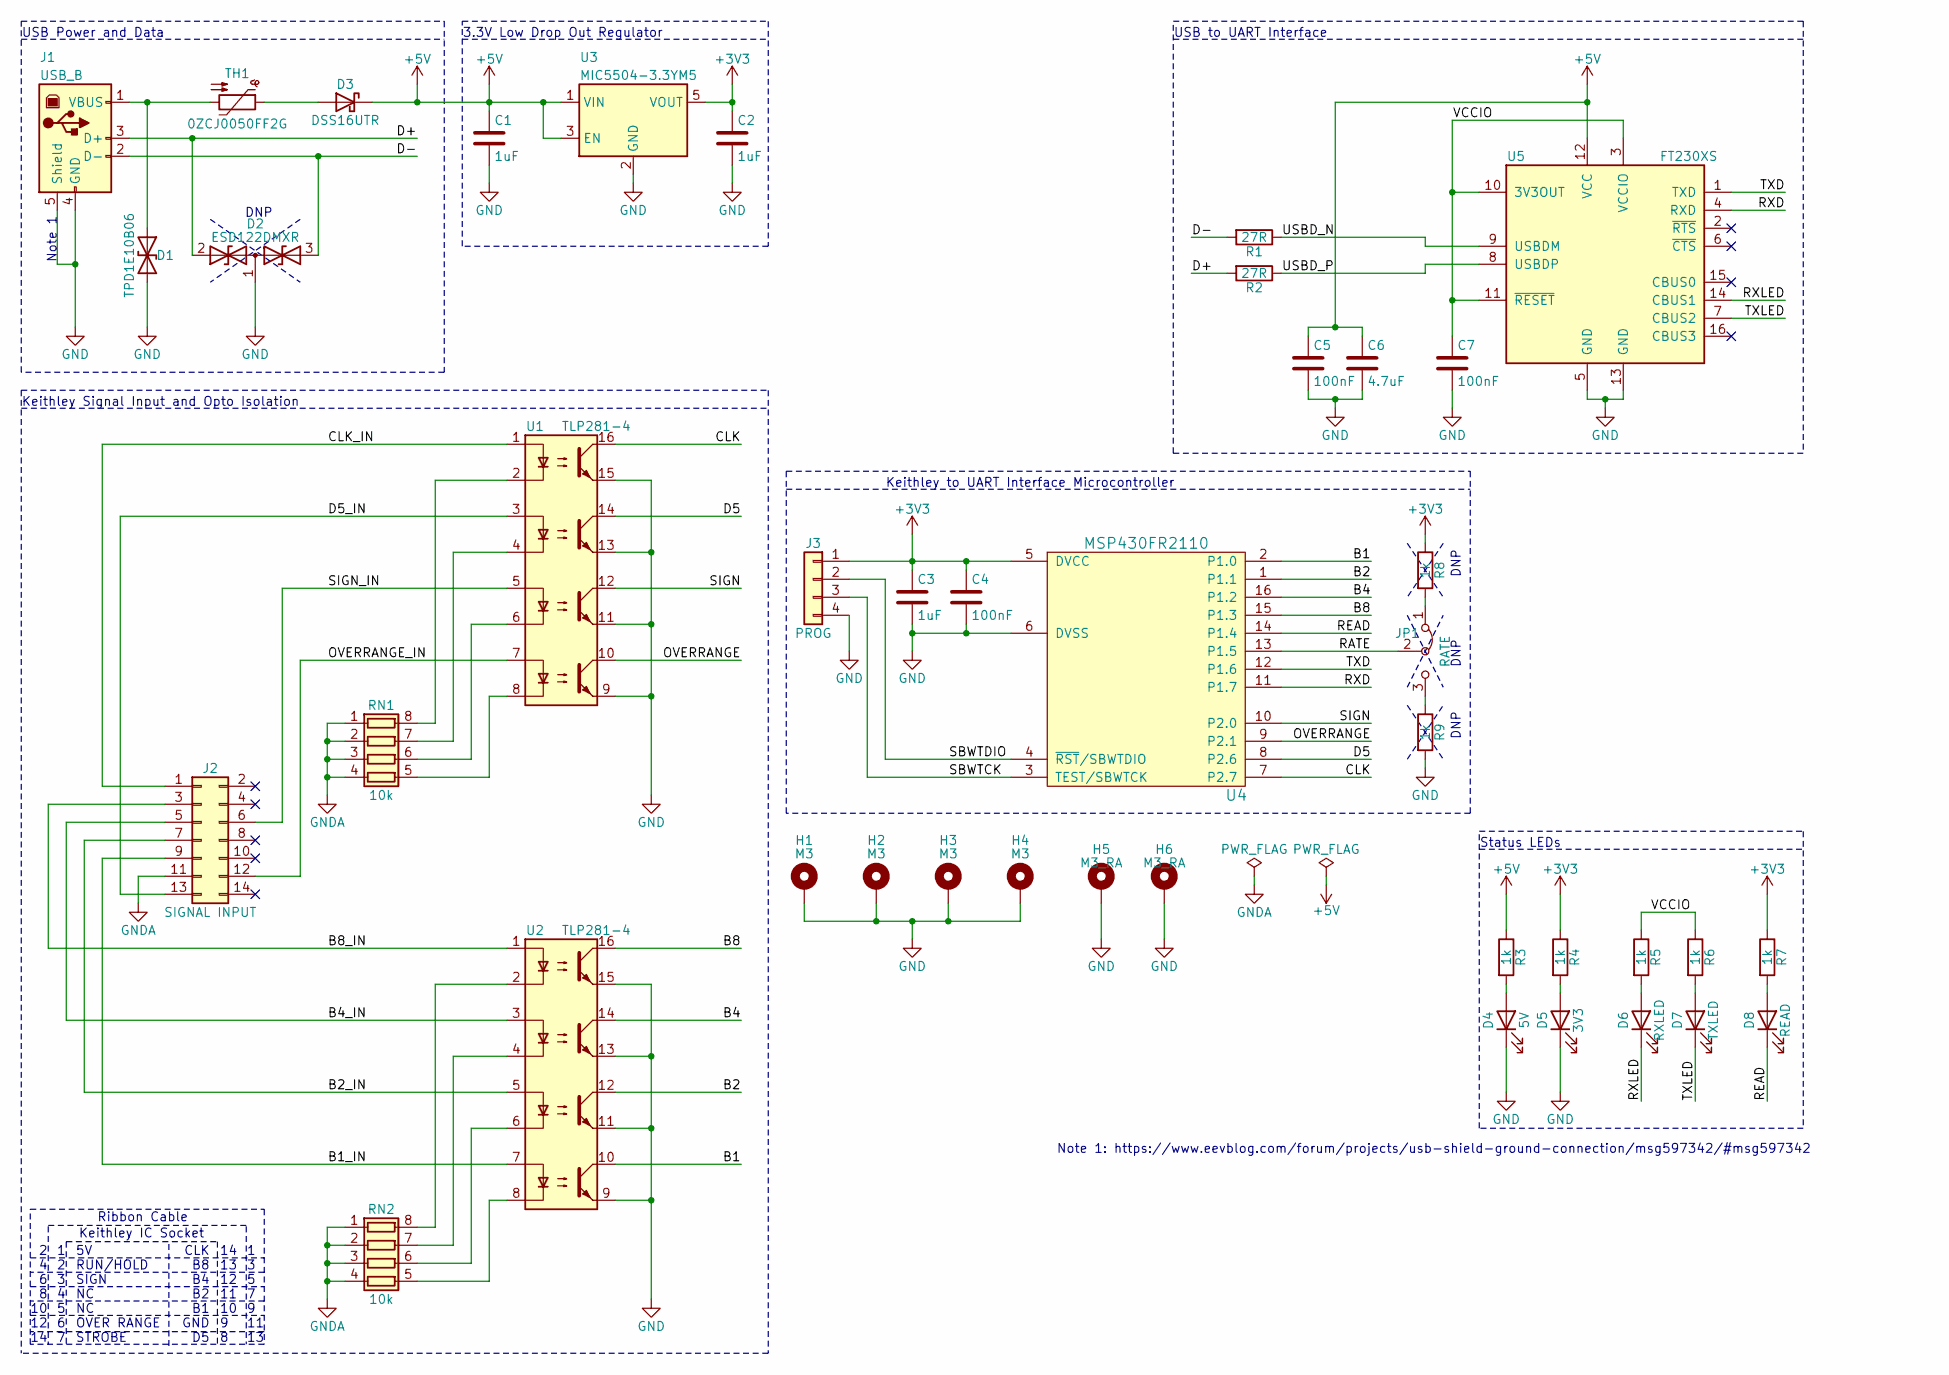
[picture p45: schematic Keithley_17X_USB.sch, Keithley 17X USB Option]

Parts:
C1, C2, C3: 1uF; C_0603_1608Metric; Mfg Part Number CL10A105KQ8NNNC
C4, C5, C7: 100nF; C_0603_1608Metric; Mfg Part Number C0603C104Z3VACTU
C6: 4.7uF; C_0603_1608Metric; Mfg Part Number CL10A475KQ8NNNC
D1: TPD1E10B06; TI_PX1SON_DPY; Mfg Part Number TPD1E10B06QDPYRQ1
D2: ESD122DMXR; TI_DMX_X2SON; Mfg Part Number ESD122DMXR
D3: DSS16UTR; D_SOD-123FL; Mfg Part Number DSS16UTR
D4: 5V; LED_0805_2012Metric; Mfg Part Number NCD0805R1
D5: 3V3; LED_0805_2012Metric; Mfg Part Number NCD0805R1
D6: RXLED; LED_0805_2012Metric; Mfg Part Number NCD0805R1
D7: TXLED; LED_0805_2012Metric; Mfg Part Number NCD0805R1
D8: READ; LED_0805_2012Metric; Mfg Part Number NCD0805R1
H1, H2, H3, H4: M3; MountingHole_3.2mm_M3_DIN965_Pad
H5, H6: M3_RA; Keystone_Screw-Terminal_7761_RightAngle; Mfg Part Number 7761
J1: USB_B; USB_B_OST_USB-B1HSxx_Horizontal; Mfg Part Number E8144-B02022-L
J2: SIGNAL INPUT; PinHeader_2x07_P2.54mm_Horizontal; Mfg Part Number 302-R141
J3: PROG; PinHeader_1x04_P2.54mm_Vertical
JP1: RATE; PinHeader_1x03_P2.54mm_Vertical
R1, R2: 27R; R_0603_1608Metric; Mfg Part Number RMCF0603JT27R0
R3, R4, R5, R6, R7, R8, R9: 1k; R_0603_1608Metric; Mfg Part Number RC0603JR-071KL
RN1, RN2: 10k; YC324-JK-0710KL; Mfg Part Number YC324-JK-0710KL
TH1: 0ZCJ0050FF2G; Fuse_1206_3216Metric; Mfg Part Number 0ZCJ0050FF2G
U1, U2: TLP281-4; SOIC-16_4.55x10.3mm_P1.27mm; Mfg Part Number TLP281-4(GB-TP,J,F
U3: MIC5504-3.3YM5; SOT-23-5; Mfg Part Number MIC5504-3.3YM5-TR
U4: MSP430FR2110; TSSOP-16_4.4x5mm_P0.65mm; Mfg Part Number MSP430FR2110IPW16R
U5: FT230XS; SSOP-16_3.9x4.9mm_P0.635mm; Mfg Part Number FT230XS-R

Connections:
+3V3: C2.1, C3.1, C4.1, J3.1, R4.1, R7.1, R8.1, U3.5 (VOUT), U4.5 (DVCC)
+5V: C1.1, C5.1, C6.1, D3.1 (K), R3.1, U3.1 (VIN), U3.3 (EN), U5.12 (VCC)
/B1: U2.10, U4.2 (P1.0)
/B1_IN: J2.9, U2.7
/B2: U2.12, U4.1 (P1.1)
/B2_IN: J2.7, U2.5
/B4: U2.14, U4.16 (P1.2)
/B4_IN: J2.5, U2.3
/B8: U2.16, U4.15 (P1.3)
/B8_IN: J2.3, U2.1
/CLK: U1.16, U4.7 (P2.7)
/CLK_IN: J2.1, U1.1
/D5: U1.14, U4.8 (P2.6)
/D5_IN: J2.13, U1.3
/D+: D2.2 (A1), J1.3 (D+), R2.2
/D-: D2.3 (A2), J1.2 (D-), R1.2
/OVERRANGE: U1.10, U4.9 (P2.1)
/OVERRANGE_IN: J2.12, U1.7
/RATE: JP1.2 (C), U4.13 (P1.5)
/READ: D8.1 (K), U4.14 (P1.4)
/RXD: U4.11 (P1.7), U5.4 (RXD)
/RXLED: D6.1 (K), U5.14 (CBUS1)
/SBWTCK: J3.3, U4.3 (TEST/SBWTCK)
/SBWTDIO: J3.2, U4.4 (~RST~/SBWTDIO)
/SIGN: U1.12, U4.10 (P2.0)
/SIGN_IN: J2.6, U1.5
/TXD: U4.12 (P1.6), U5.1 (TXD)
/TXLED: D7.1 (K), U5.7 (CBUS2)
/USBD_N: R1.1, U5.9 (USBDM)
/USBD_P: R2.1, U5.8 (USBDP)
/VCCIO: C7.1, R5.1, R6.1, U5.3 (VCCIO), U5.10 (3V3OUT), U5.11 (~RESET)
GND: C1.2, C2.2, C3.2, C4.2, C5.2, C6.2, C7.2, D1.2 (A2), D2.1 (common), D4.1 (K), D5.1 (K), H1.1, H2.1, H3.1, H4.1, H5.1, H6.1, J1.4 (GND), J1.5 (Shield), J3.4, R9.2, U1.9, U1.11, U1.13, U1.15, U2.9, U2.11, U2.13, U2.15, U3.2 (GND), U4.6 (DVSS), U5.5 (GND), U5.13 (GND)
GNDA: J2.11, RN1.1 (R1.1), RN1.2 (R2.1), RN1.3 (R3.1), RN1.4 (R4.1), RN2.1 (R1.1), RN2.2 (R2.1), RN2.3 (R3.1), RN2.4 (R4.1)
unnamed: D1.1 (A1), J1.1 (VBUS), TH1.2
unnamed: D3.2 (A), TH1.1
unnamed: D4.2 (A), R3.2
unnamed: D5.2 (A), R4.2
unnamed: D6.2 (A), R5.2
unnamed: D7.2 (A), R6.2
unnamed: D8.2 (A), R7.2
unnamed: JP1.1 (A), R8.2
unnamed: JP1.3 (B), R9.1
unnamed: RN1.5 (R4.2), U1.8
unnamed: RN1.6 (R3.2), U1.6
unnamed: RN1.7 (R2.2), U1.4
unnamed: RN1.8 (R1.2), U1.2
unnamed: RN2.5 (R4.2), U2.8
unnamed: RN2.6 (R3.2), U2.6
unnamed: RN2.7 (R2.2), U2.4
unnamed: RN2.8 (R1.2), U2.2

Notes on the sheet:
USB Power and Data
USB to UART Interface
Keithley to UART Interface Microcontroller
3.3V Low Drop Out Regulator
Keithley Signal Input and Opto Isolation
Status LEDs
5V RUN/HOLD SIGN NC NC OVER RANGE STROBE
CLK B8 B4 B2 B1 GND D5
1 2 3 4 5 6 7
14 13 12 11 10 9 8
2 4 6 8 10 12 14
1 3 5 7 9 11 13
Keithley IC Socket
Ribbon Cable
Note 1
Note 1: https://www.eevblog.com/forum/projects/usb-shield-ground-connection/msg597342/#msg597342
DNP

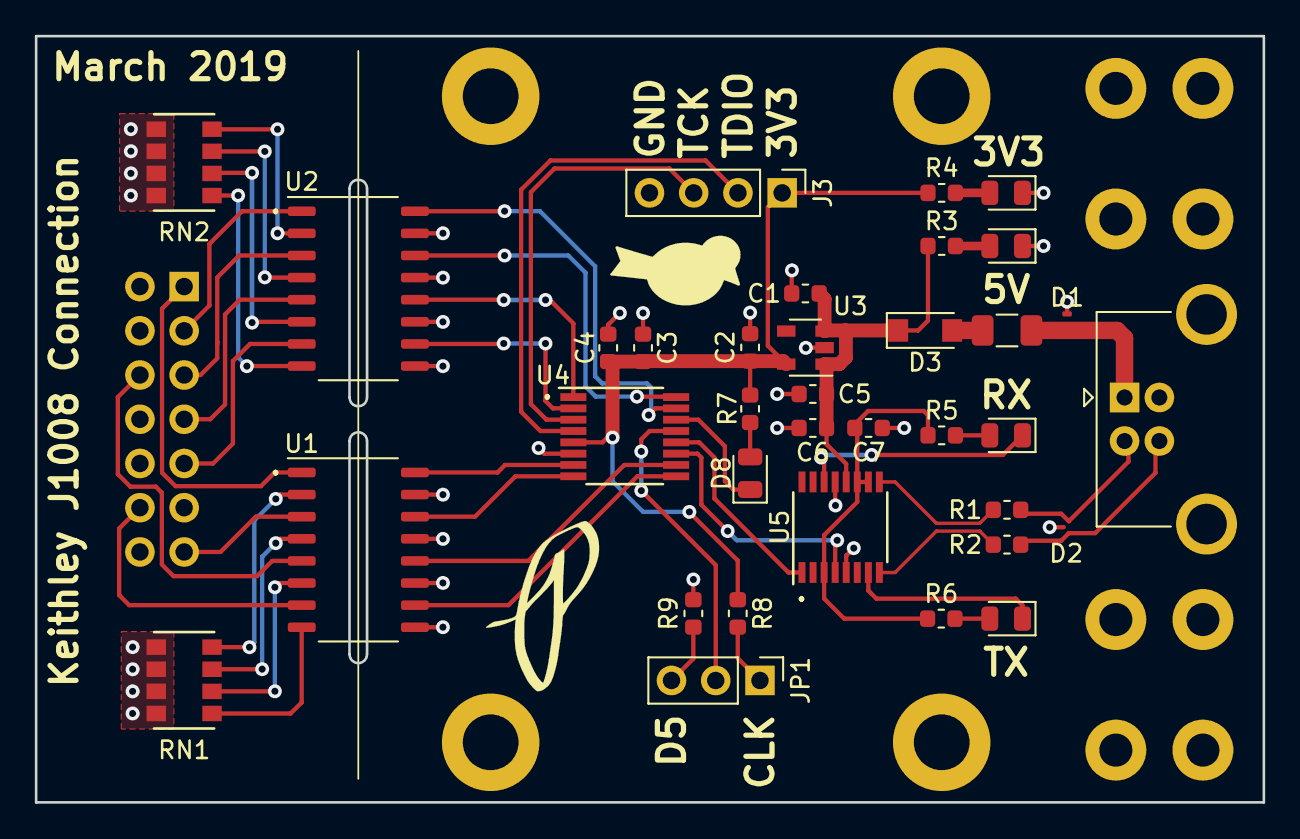
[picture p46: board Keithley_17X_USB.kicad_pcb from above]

Board: 2 copper layers, 70.5 x 44.0 mm, 42 parts (1 on the bottom side), 50 nets.

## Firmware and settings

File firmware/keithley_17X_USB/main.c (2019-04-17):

/* main.c
 *
 * Created on: Feb 9, 2019
 *      Author: Sam
 *
 * Firmware for Keithley 17X USB option
 */

#include <msp430.h> 
#include <stdint.h>
#include "uart.h"
#include "clock.h"
#include "gpio.h"
#include "delay.h"
#include "keithley.h"

char reading[] = { " \n\r00000+" };             // this is the reading from the Keithley meter
                                                // this string is backwards to optimize for loops per TI advise
int main(void)
{
    WDTCTL = WDTPW | WDTHOLD;                   // Stop watchdog timer
    SFRRPCR |= SYSRSTRE | SYSRSTUP;             // Enable internal pullup resistor on reset pin
    Init_CLK();                                 // Set main clock to 16MHz
    Init_GPIO();                                // Configure GPIO

    PM5CTL0 &= ~LOCKLPM5;                       // Disable the GPIO power-on default high-impedance mode
                                                // to activate previously configured port settings
    Init_UART();

    TB0CCTL0 |= CCIE;                           // TBCCR0 interrupt enabled
    TB0CCR0 = 32000;                            // should interrupt at ~2ms [500Hz]
    TB0CTL = TBSSEL__SMCLK | MC__STOP;          // SMCLK=16MHz, don't start yet

    while (1)
    {
        P2IFG &= ~BIT6;                         // clear pending interrupts
        P2IE |= BIT6;                           // enable interrupt on P2.6, Keithley D5

        __bis_SR_register(LPM3_bits | GIE);     // Enter LPM3, interrupts enabled
        delay_512us();                          // delay so reading is near middle of signals
        TB0CTL ^= MC__UP;                       // toggle timer on

        read_databus(reading);                  // read Keithley databus and save to reading

        TB0CTL ^= MC__UP;                       // toggle timer off

        UART_print(reading, sizeof(reading));   // Send reading via UART
    }
}

// =============================================
// INTERUPT VECTORS LIE BELOW, CAUTION THEY BYTE!
// =============================================


// P2 interrupt, triggered by P2.6 rising edge
#pragma vector=PORT2_VECTOR
__interrupt void PORT2_ISR(void)
{
    P2IE &= ~BIT6;                              // disable any further interrupts
    __bic_SR_register_on_exit(LPM3_bits);       // Exit LPM3
}

#if defined(__TI_COMPILER_VERSION__) || defined(__IAR_SYSTEMS_ICC__)
#pragma vector=USCI_A0_VECTOR
__interrupt void USCI_A0_ISR(void)
#elif defined(__GNUC__)
void __attribute__ ((interrupt(USCI_A0_VECTOR))) USCI_A0_ISR (void)
#else
#error Compiler not supported!
#endif
{
    switch (__even_in_range(UCA0IV, USCI_UART_UCTXCPTIFG))
    {
    case USCI_NONE:
        break;
    case USCI_UART_UCRXIFG:                     // Receive interrupt flag, set when UCA0RXBUF receives a char
        break;
    case USCI_UART_UCTXIFG:                     // Transmit interrupt flag, set when UCA0TXBUF empty
        __bic_SR_register_on_exit(LPM3_bits);   // Exit LPM3
        break;
    case USCI_UART_UCSTTIFG:
        break;
    case USCI_UART_UCTXCPTIFG:
        break;
    default:
        break;
    }
}

// Timer B0 interrupt service routine
#if defined(__TI_COMPILER_VERSION__) || defined(__IAR_SYSTEMS_ICC__)
#pragma vector = TIMER0_B0_VECTOR
__interrupt void Timer_B (void)
#elif defined(__GNUC__)
void __attribute__ ((interrupt(TIMER0_A0_VECTOR))) Timer_A (void)
#else
#error Compiler not supported!
#endif
{
    __bic_SR_register_on_exit(LPM3_bits);       // Exit LPM3
}

// WDT interrupt service routine
#if defined(__TI_COMPILER_VERSION__) || defined(__IAR_SYSTEMS_ICC__)
#pragma vector = WDT_VECTOR
__interrupt void WDT_ISR(void)
#else
#error Compiler not supported!
#endif
{
    WDTCTL = WDTPW + WDTHOLD;                   // Stop WDT
    __bic_SR_register_on_exit(LPM3_bits);       // Exit LPM3
}

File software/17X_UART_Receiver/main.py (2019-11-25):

''' Create a main GUI with buttons to lauch individual GUIs for each Keithley Model Number
    November 2019
'''

# Import tkinter items but only what is used
from tkinter import Tk
from tkinter import Label, Button, Toplevel

from keithley import keithley_gui

def start_k179():
    ''' Start the GUI for Keithley 179 Digital Multimeter
    '''
    k179_window = Toplevel(root)
    k179_gui = keithley_gui(k179_window, model_number=179)
    return

def start_k177():
    ''' Start the GUI for Keithely 177 Digital Multimeter
    '''
    k177_window = Toplevel(root)
    k177_gui = keithley_gui(k177_window, model_number=177)
    return

def exit_gui():
    ''' Exit all
    '''
    root.destroy()

if __name__ == "__main__":
    root = Tk()
    root.title("Keithley 17X USB Adapter")
    root.minsize(320,180)

    # text
    top_label = Label(root, text=" ")
    top_label.pack()

    # button
    Keithley_179 = Button(root, text="Keithley 179", width=20, height=2, command=start_k179)
    Keithley_179.pack()

    Keithley_177 = Button(root, text="Keithley 177", width=20, height=2, command=start_k177)
    Keithley_177.pack()

    quit_button = Button(root, text='Quit', width=20, height=2, command=exit_gui)
    quit_button.pack()
    
    root.mainloop()

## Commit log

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2019-02-10 start schematic
    [Keithley_17X_USB.kicad_pcb, Keithley_17X_USB.sch]
2019-02-11 added more stuff!
    [Keithley_17X_USB.sch]
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2019-02-14 clean up schematic, final or darn close
    [Keithley_17X_USB.sch]
2019-02-15 add component feild values
    [Keithley_17X_USB.sch]
2019-02-16 create PX1SON 3d model
    [TI_PX1SON.FCStd, TI_PX1SON.step]
2019-02-16 create XSON 3d model
    [TI_XSON_DMX.FCStd, TI_XSON_DMX.step]
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2019-02-16 update with footprints
    [Keithley_17X_USB.sch]
2019-02-18 create file
    [SMC_DSS16UTR.FCStd, SMC_DSS16UTR.step]
2019-02-18 add more footprints and 3d models
    [Keithley_17X_USB.sch]
2019-02-18 add r_array footprint and 3d model
    [Keithley_17X_USB.sch, YAG_YC324-L.step, YAG_YC324-M.step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]
2019-02-18 add right angle mounting holes
    [Keithley_17X_USB.sch]
2019-02-18 save changes
    [SMC_DSS16UTR.FCStd, YAG_YC324.FCStd]
2019-02-19 create 3d model
    [Keystone_7761.FCStd, Keystone_7761.step]
2019-02-19 add right angle mount
    [Keithley_17X_USB.sch]
2019-02-20 added rate selection, trigger on clk or D5. Future implementation
    [Keithley_17X_USB.sch]
2019-02-20 change TH1 name to part number
    [Keithley_17X_USB.sch]
2019-02-23 add usb connector 3d model
    [USB_B_RightAngle.FCStd, USB_B_RightAngle.step]
2019-02-24 add missing 3d models
    [0ZCJ.FCStd, 0ZCJ.step, SOIC-16_3.9x9.9mm_P1.27mm.step]
2019-02-24 rearaned B1 B2 B4 and B8 connection to opto for better layout
    [Keithley_17X_USB.kicad_pcb, Keithley_17X_USB.sch]
2019-02-24 update 3d model to shrouded header
    [Header_14pos_2rows_RightAngle_Shrouded.FCStd, Header_14pos_2rows_RightAngle_Shrouded.step, Keithley_17X_USB.kicad_pcb]
2019-02-24 update with proper colors
    [SMC_DSS16UTR.FCStd, SMC_DSS16UTR.step, TI_PX1SON.FCStd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]
2019-02-24 lable right side of usb data lines for differential pair routing
    [Keithley_17X_USB.sch]
2019-02-24 connect usb sheild to ground
    [Keithley_17X_USB.sch]
2019-02-24 ground right angle mounts
    [Keithley_17X_USB.sch]
2019-02-24 rename usb differential pairs to what kicad expects
    [Keithley_17X_USB.sch]
2019-02-24 label VCCIO net
    [Keithley_17X_USB.sch]
2019-02-24 rx/tx leds powered using vccio
    [Keithley_17X_USB.sch]
2019-02-26 shrink length by 15mm
    [Keithley_17X_USB.kicad_pcb]
2019-02-26 rearange Port 2 connections to simplfy layout
    [Keithley_17X_USB.sch]
2019-03-01 draft layout, need to cleanup and make pretty
    [Keithley_17X_USB.kicad_pcb]
2019-03-10 remove reference to missing fuse 3d model
    [Keithley_17X_USB.kicad_pcb]
2019-03-10 added small flat on side for assembly
    [Keithley_Case_Top.FCStd]
2019-03-10 update silkscreen
    [Keithley_17X_USB.kicad_pcb]
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2019-03-19 minor silkscreen cleanup
    [Keithley_17X_USB.kicad_pcb]
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2019-03-19 reduce flood fill outside board outline
    [Keithley_17X_USB.kicad_pcb]
2019-03-23 add vertical center line
    [Keithley_17X_USB.kicad_pcb]
2019-03-24 shift z-axis zero to bottom of part
    [Keithley_17X_USB_Bottom.FCStd]
2019-03-24 adjust stock for 1mm below z-axis for cleanup
    [Keithley_17X_USB_Bottom.FCStd]
2019-03-24 moved enclosure CAD files to descriptive directory
    [Keithley_17X_USB_Assembly.FCStd, Keithley_17X_USB_Bottom.FCStd, Keithley_17X_USB_Top.FCStd]
2019-03-24 split CAD models so that assembly workbench is happy
    Assembly 2 is unable to use files with CAM featrues, sees as multiple models and complains
    [CAM_Keithley_17X_USB_Bottom.FCStd, CAM_Keithley_17X_USB_Top.FCStd, Keithley_17X_USB_Bottom.FCStd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]
2019-03-24 add to and bottom
    [Keithley_17X_USB_Assembly.FCStd]
2019-03-24 move and rename instruemtn case model
    [Keithley_17X_Instrument_Case_Top.FCStd]
2019-03-24 modify with mounting holes for USB
    [Keithley_17X_Instrument_Case_Top.FCStd]
2019-03-24 add instument case, calibration, and face plate
    [Keithley_17X_USB_Assembly.FCStd]
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2019-03-24 update with new faceplate thicnkess
    [Keithley_17X_USB.kicad_pcb]
2019-03-24 add viewign window to instument case to see inside
    [Keithley_17X_Instrument_Case_Top.FCStd, Keithley_17X_USB_Assembly.FCStd]
2019-03-25 update to KiCad 5.1
    [Keithley_17X_USB.sch]
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2019-04-06 not CNC machining faceplate
    [CAM_Keithley_17X_USB_Face.FCStd]
2019-04-06 add 2d drawings of enclosure and face plate
    [Keithley_17X_USB_Assembly.FCStd]
2019-04-06 update pocket cutout type to zigzagOffset. Set new tool info
    [CAM_Keithley_17X_USB_Bottom.FCStd, CAM_Keithley_17X_USB_Top.FCStd]
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2019-04-17 DNP R8, R9, and JP1
    [Keithley_17X_USB.sch]
2019-04-21 reduced step depth to 0.06inch
    [CAM_Keithley_17X_USB_Top.FCStd]
2019-04-21 reduce feeds to 1.5mm/s
    [CAM_Keithley_17X_USB_Top.FCStd]
2019-10-26 move pcb files to dir
    [0ZCJ.FCStd, 0ZCJ.step, Header_14pos_2rows_RightAngle_Shrouded.FCStd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]
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2019-11-22 add radio buttons for units, not working yet
    [main.py]
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2020-05-15 increase USB cuttout size
    [Keithley_17X_USB_Face.FCStd]
2020-05-15 move to FreeCAD dir
    [Keithley_17X_Instrument_Calibration_Shield.FCStd, Keithley_17X_Instrument_Case_Top.FCStd, Keithley_17X_USB_Assembly.FCStd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]
2020-05-15 add files for 3d printing
    [USB_face_plate.amf, USB_face_plate.stl]
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2020-05-16 add LEDs part number
    [Keithley_17X_USB.sch]
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

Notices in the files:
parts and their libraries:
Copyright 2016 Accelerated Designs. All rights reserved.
